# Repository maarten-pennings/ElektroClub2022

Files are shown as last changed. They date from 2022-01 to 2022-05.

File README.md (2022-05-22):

# ElektroClub2022

End-of-year project (2022) for the ElektroClub.

## Introduction

In my village I'm volunteer for an "ElectroClub" for children 8 to 12 years.
At the end of the (school) year we try to have a master piece for them, to remember the club.
In 2022 we wanted the year digits with flashing numbers; this is actually a copy of an old project:

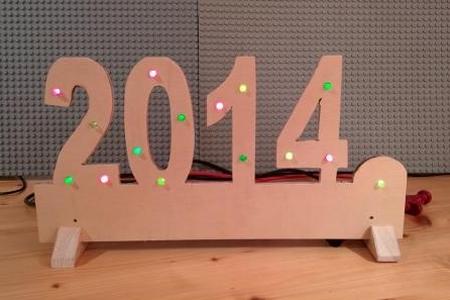
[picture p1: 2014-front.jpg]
front
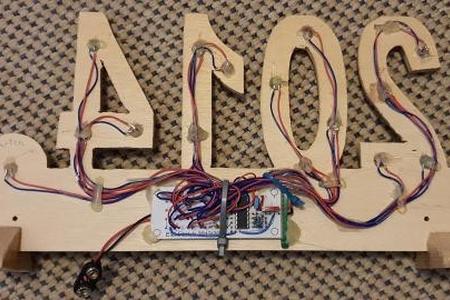
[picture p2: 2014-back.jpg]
back
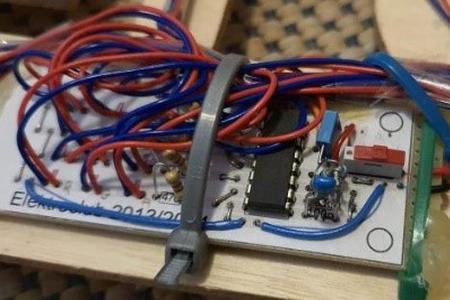
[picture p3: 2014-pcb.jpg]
pcb
  

What we remembered from 2014 is that creating the wooden panels, soldering all the LED wires, 
and gluing all wires in place, was too time consuming.
This year we will try a variation: designing the PCB using [EasyEDA](https://easyeda.com)
and manufacturing it via [JLCPCB](https://jlcpcb.com/). 
The biggest challenge is to get a nice rendering of the big digits 2022.

We have minutes of the project in [Word](ElektroClub2022-plan.docx) or [pdf](ElektroClub2022-plan.pdf) - sorry they are in Dutch.

## Schematics

The 2014 schematics were lost in time, so we needed to do some googling.
The heart of the circuit is the [4060 binary counter](https://www.ti.com/lit/ds/symlink/cd4060b.pdf):

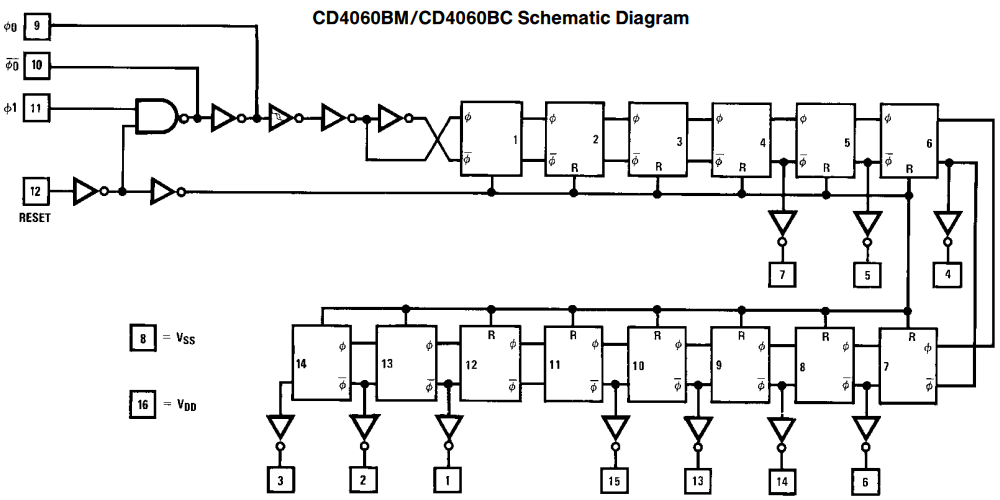
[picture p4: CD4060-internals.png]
4060 internals


The schematics is based on one from [buildcircuit](https://www.buildcircuit.com/diy-kit-8-happy-birthday-led-flashing-diy-kit-using-cd4060-and-music-chip/).
However, we have 5 groups of LEDs, not three. And we added some capacitors for stabilization.

We will use the 4060 outputs to flash the LEDs; here are some time [calculations](timing.xlsx).

We were initially puzzled by the diodes, we now believe they form a "wired OR", 
resetting the CD4060 when all three (five) transistor basis are high.
This is when the CD4060 reaches 0b...111 (0b...11111). 
In that situation all LEDs are off. 

In other words at the same moment all LEDs are switched off, 
the CD4060 is reset and outputs 0b...0000 and all LEDs are on.

Our final [schematic](schematic.pdf).

## Stand

I wanted the PCB to have small feet.
I made a [3D model](standmodel) to check the positions and lengths of the slots.

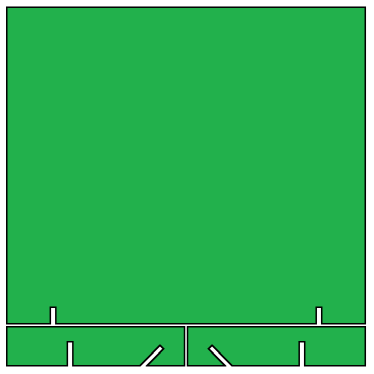
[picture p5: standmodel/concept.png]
slots
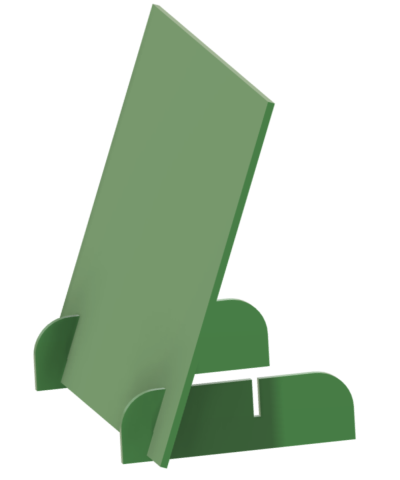
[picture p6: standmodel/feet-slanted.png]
model


## PCB (with fancy board outline and silk print)

A step that took quite some time was the [design](pcboutline) of the board outline.
This includes the big "2022" digits, that I wanted to cut out.
I made the design in Visio, because that can save to DXF, the format needed by the PCB tool.

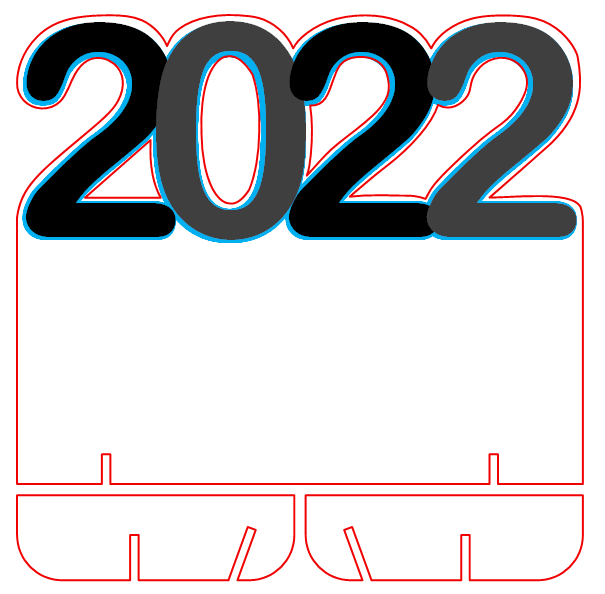
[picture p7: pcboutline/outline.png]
outline


The resulting PCB as a render, front and back side.

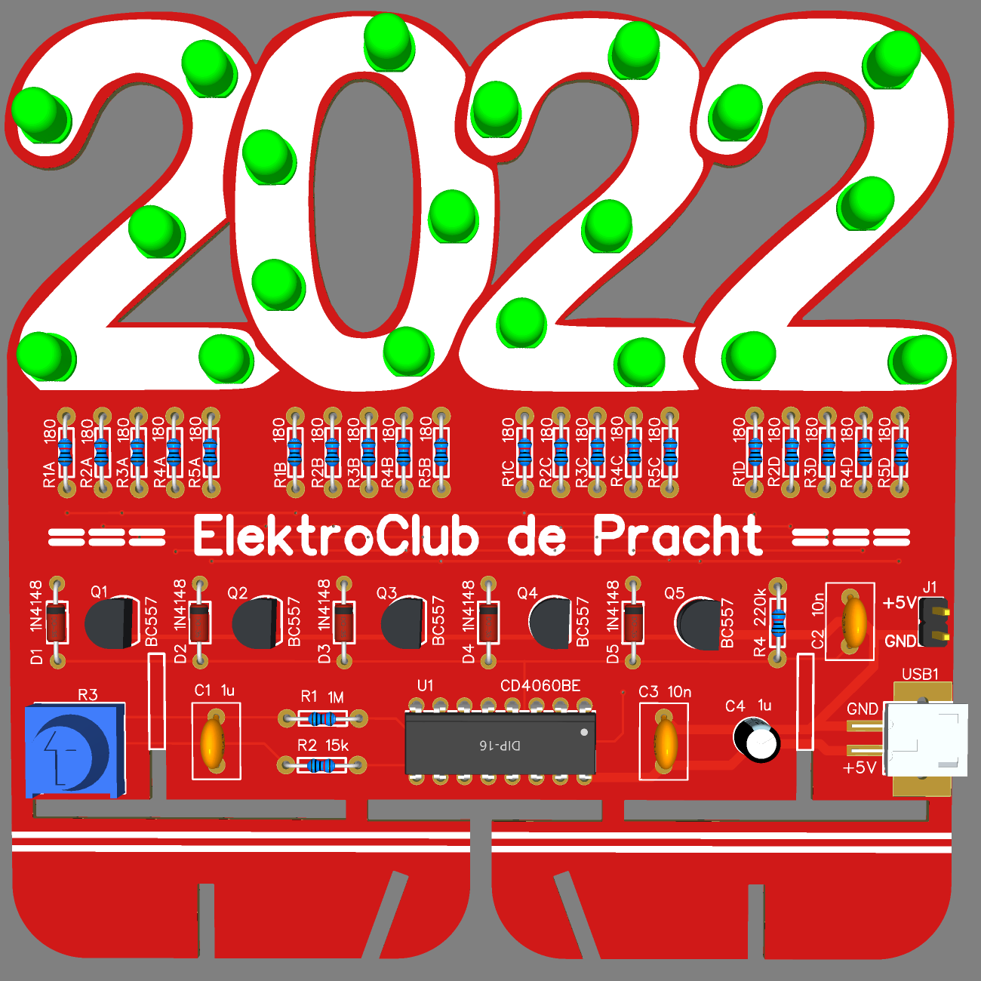
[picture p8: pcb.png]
PCB


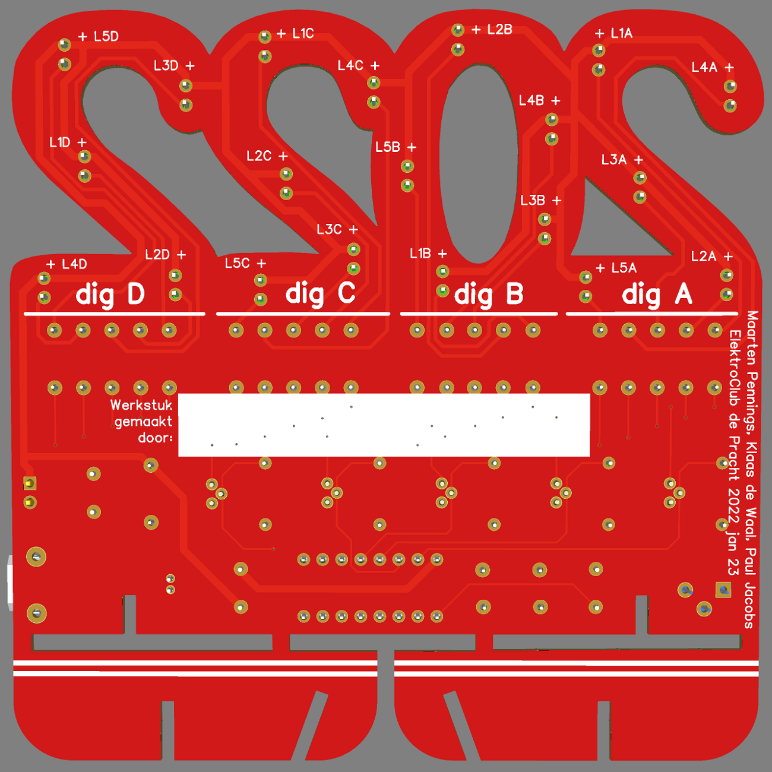
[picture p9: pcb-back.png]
PCB backside


Find the whole design on [oshwlab](https://oshwlab.com/maartenpennings/elektroclub2022).
The [gerber](Gerber_ElektroClub2022_pcb.zip) is also available separately.

## Order

I ordered 5 red, 10 green and 5 black at [JLCPCB](https://jlcpcb.com/); 
pricing: €1.76, €4.41, €3.53 respectively plus €15.85 shipping. Total €25.55.

The resulting PCBs are great looking. 

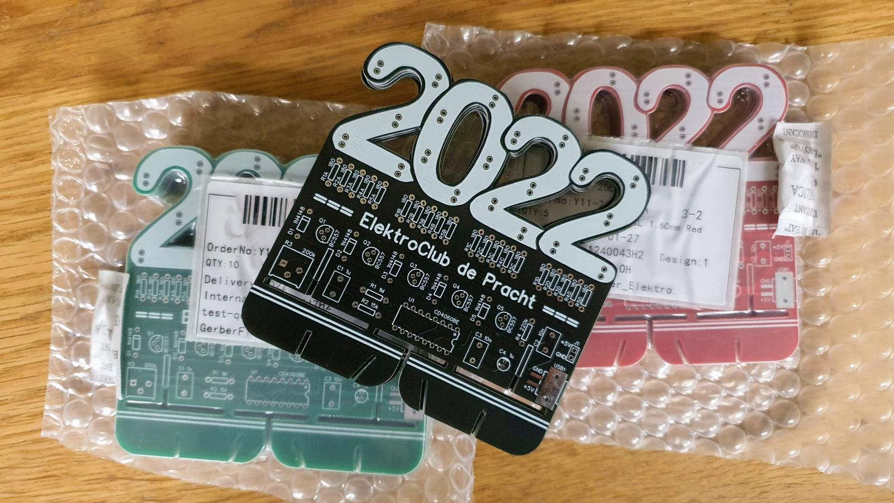
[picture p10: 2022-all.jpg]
PCBs


## Cost 

Find below the cost of the boards and components.
The LEDs, transistors, and resistors came from our stock, so I have added "guessed" prices.
We might have ordered too few IC sockets and/or USB connectors.

  | ID |      Name	     | Designator      |Quantity | For 20 boards | Stock (guessed) | Ordered  |
  |:--:|:---------------:|:---------------:|:-------:|:-------------:|:---------------:|:--------:|
  |  1 |  1u (ceramic )  | C1              | 1       |       20      |                 | [100(+100) for €3.02](https://www.aliexpress.com/item/1005001715033995.html) |
  |  2 |      10n        | C2,C3           | 2       |       40      |                 | 100 with (1) |
  |  3 |   1u (elco)     | C4              | 1       |       20      |                 | [50 for €1.90](https://www.aliexpress.com/item/1005002842732971.html) |
  |  4 |     1N4148      | D1,D2,D3,D4,D5  | 5       |      100      |                 | [200 for €2.01](https://www.aliexpress.com/item/1005003540554760.html) |
  |  5 | HDR-M-2.54_1x2  | J1              | 1       |       20      |    Not mounted  | Not mounted |
  |  6 | LED-TH-5mm      | L1A,L1B,L1C,L1D |         |               |                 | |
  |    |                 | L2A,L2B,L2C,L2D |         |               |                 | |
  |    |                 | L3A,L3B,L3C,L3D |         |               |                 | |
  |    |                 | L4A,L4B,L4C,L4D |         |               |                 | |
  |    |                 | L5A,L5B,L5C,L5D | 20      |      400      | [500 for €4.66](https://www.aliexpress.com/item/1005003483614644.html) | |
  |  7 |     BC557       | Q1,Q2,Q3,Q4,Q5  | 5       |      100      | [100 for €2.24](https://www.aliexpress.com/item/32868211649.html) | |
  |  8 |       1M        | R1              | 1       |       20      | [100(+100+100+100) for €3.80](https://www.aliexpress.com/item/32979849787.html) | |
  |  9 |      180        | R1A,R1B,R1C,R1D |         |               |                 | |
  |    |                 | R2A,R2B,R2C,R2D |         |               |                 | |
  |    |                 | R3A,R3B,R3C,R3D |         |               |                 | |
  |    |                 | R4A,R4B,R4C,R4D |         |               |                 | |
  |    |                 | R5A,R5B,R5C,R5D | 20      |      400      |    100 with (8) | |
  | 10 |      15k        | R2              | 1       |       20      |    100 with (8) | |
  | 11 | 200k (potmeter) | R3              | 1       |       20      |                 | [25 for €5.48](https://www.aliexpress.com/item/32783054938.html) |
  | 12 |     220k        | R4              | 1       |       20      |    100 with (8) | |
  | 13 |   CD4060BE      | U1              | 1       |       20      |                 | [30 for €2.52](https://www.aliexpress.com/item/1005001345739246.html) |
  | 14 |micro USB (2 pin)| USB1            | 1       |     **20**    |                 | [**20** for €2.00](https://www.aliexpress.com/item/32931657320.html) |
  | 15 |  dip 16 socket  | (U1)            | 1       |     **20**    |                 | [**20** for €1.75](https://www.aliexpress.com/item/1005001403007175.html) |
  | 16 |  ziplock bags   | -               | 1       |       20      |                 | [100 for €3.64](https://www.aliexpress.com/item/1005003813481837.html) |
  | 17 |      pcb        | -               | 1       |       20      |                 | [20 for €25.55](https://oshwlab.com/maartenpennings/elektroclub2022) |
  |    |                 |                 |         |               |          €10.70 | **€47.87** |
  |    |                 |                 |         |               |                 | €58.57 (**€2.93/piece**) |

## Instructions

There is an instruction leaflet for assembling the PCB:
a [doc](ElektroClub2022-manual.docx) or [pdf](ElektroClub2022-manual.pdf) version.
Since the leaflet is for the children, it is in Dutch.

## Final result

The assembled board looks like this (sorry, potmeter is on backorder).

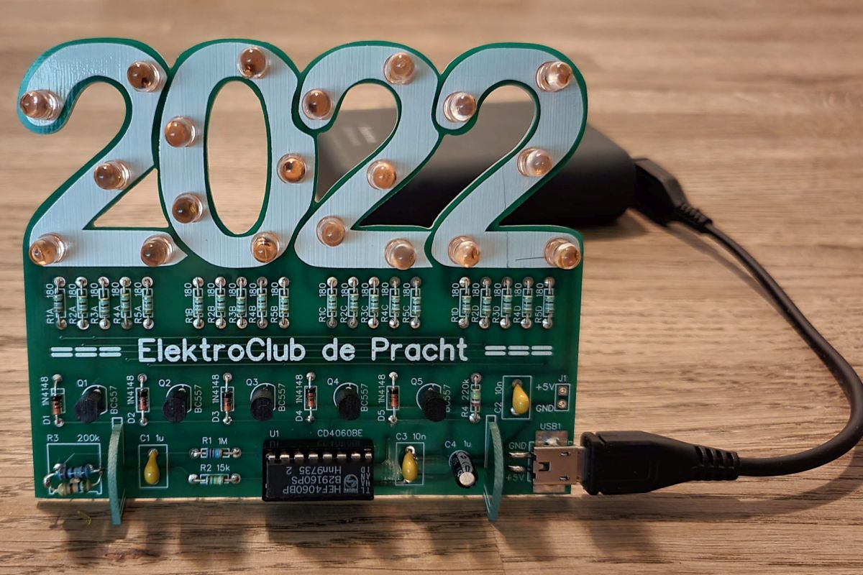
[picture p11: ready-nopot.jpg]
Ready no pot


For a video check [YouTube](https://www.youtube.com/watch?v=dqfvwsGTvYA).

## Problems

The result (see video) looks ok, but we found some [issues](debug).

(end)

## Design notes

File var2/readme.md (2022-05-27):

# Variant 2

The CD4060 is hard to obtain, the reset circuit is hard to get correct, 
the blinking patterns are not very random. Why not replace the CD4060 with an ATtiny85.

## Firmware

I wrote the [multiblink](multiblink) firmware.
It is tested on Nano and ATtiny85.

I used a [Nano to flash](https://makersportal.com/blog/2018/5/19/attiny85-arduino-board-how-to-flash-the-arduino-bootloader-and-run-a-simple-sketch) the ATtiny85.

## Schematics

The ATtiny85 has 8 pins, 2 are for power, one is for reset, so 5 left.
We have 5 groups of LEDs, so they can be hooked to those 5 GPIO pins.

However, we wanted a switch to control the speed or blinking pattern.
The first idea was to use the RESET pin for that. 
But once the RESET pin is reprogrammed, it is hard to reflash the ATtiny85.

Instead we opted for time multiplexing, the output pins, using them also for input.

See the [schematics](Schematic_ElektroClub2022tiny.pdf).

## Breadboard

The ATtiny85 with firmware, group drivers and switches is tested on a breadboard.
Here is demo [video](https://www.youtube.com/watch?v=RSclDXem_cg).
Speed varies over 100ms, 200ms, 400ms, 800ms, 1600ms, 3200ms, and 6400ms.
Patterns are ALL, HALF024, HALF34, BIN, WALK1, WALK2, WALK3, RND, RNDHI.

## In-situ

Next step was to test the ATtiny in the actual PCB. I took out the 4060
and wired the 4060 pins to a breadboard with the ATtiny85 (and the two switches).

The lower switch controls pattern mode: 
flash ALL, HALF (0+1+2 then 3+4), BINARY, WALK1, WALK2, FILL, RND, RNDMED (min 2 leds on, max 3). 
The upper switch controls the blink time 100, 200, 400, 800, 1600, 3200, and 6400ms. 

This is the [video](https://youtu.be/QG9YBovyWns).

## Impression

A possible impression for the new PCB

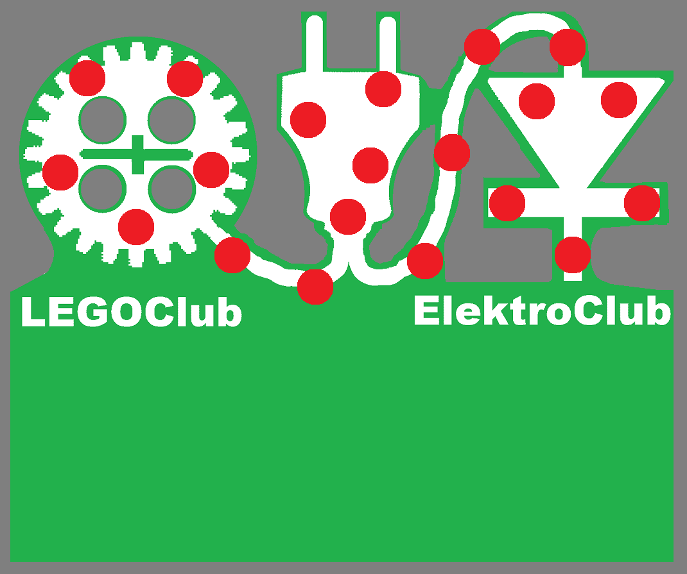
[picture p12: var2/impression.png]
Impression


(end)

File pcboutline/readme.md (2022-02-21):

# PCB outline

Non-rectangular board outline and fancy silk print
in [EasyEDA](https://easyeda.com) and [JLCPCB](https://jlcpcb.com/). 

Find the design on [oshwlab](https://oshwlab.com/maartenpennings/elektroclub2022).

## Introduction

We want big digits.
Those digits need to stand out.
We achieve this in two ways:
 - partially "cut them out", i.e. complex PCB outline
 - "paint" them, either via silk print or via metal
 
[EasyEDA](https://easyeda.com) has an import mechanism for both.
For an outline, it needs a vector description via a so-called [DXF file](https://en.wikipedia.org/wiki/AutoCAD_DXF).

For the silk print it needs a bitmap via a jpg, png, gif, bmp or SVG file.

I had one tool that support both, VISIO.

## Visio

I've drawn the 4 digits in Visio using "Arial Rounded MT Bold" at 150pt.
At this size, the four digits span 100mm, the target width of the PCB.

I rendered the digits twice, once bold (blue) and once non-bold (black/gray).
The black/gray will be exported as png for EasyEDA silk screen.

I used the blue as a reference for a hand crafted outline.
The blue (bold) was a bit bigger than black (non-bold) but not much bigger, 
so my handcrafted outline (Visio line tool) is about 1mm away from the blue.
The drawing includes the slots and the feet from the 3D model.

Here is a visualisation of the [Visio](outline.vsdx) drawing

Outline.

I did two separate exports, the red lines to a [DXF file](outline.dxf)
and the black/gray digits to a [png file](letters.png).

## Outline

The outline (and especially board cut-outs are the hardest).
In the [EasyEDA](https://easyeda.com) PCB editor, import the DXF file.

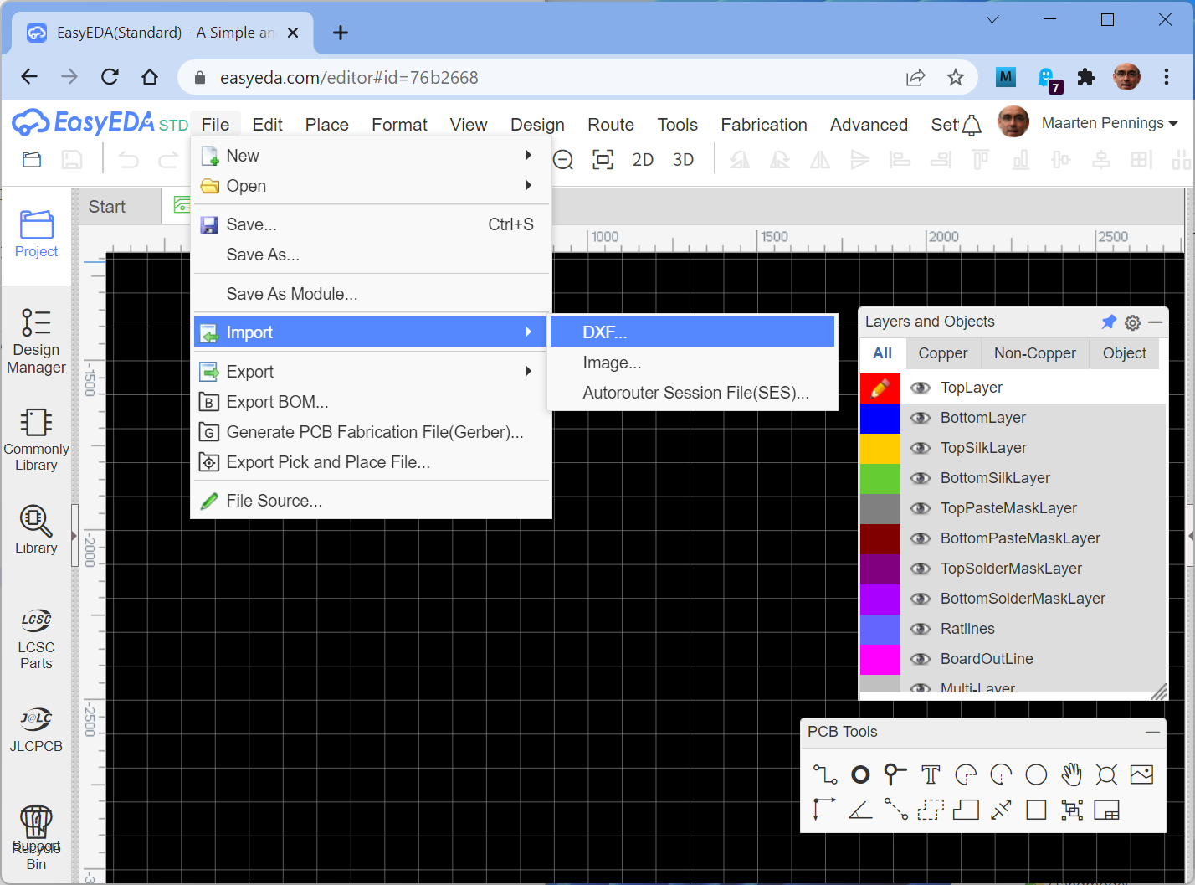
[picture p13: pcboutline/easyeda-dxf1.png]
Outline - dialog


Press `Select a DXF file...` and browse to `outline.dxf`.
Also make sure to import on layer `BoardOutLine`.

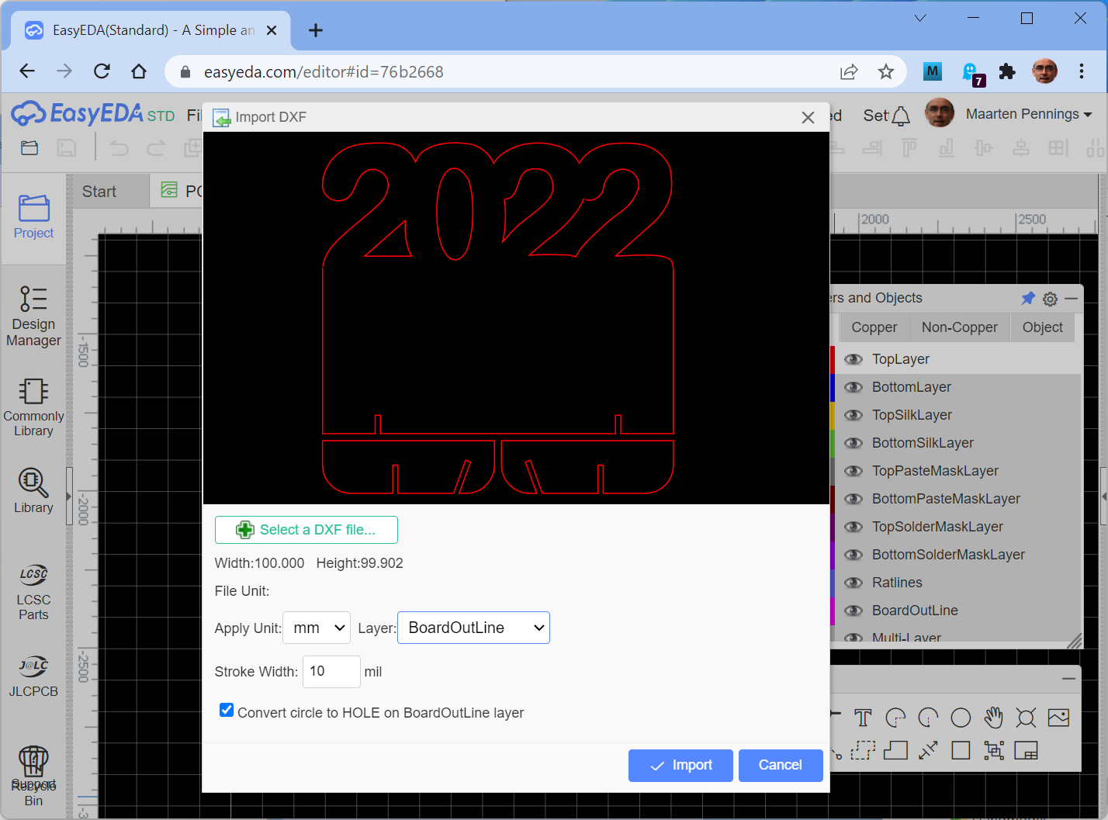
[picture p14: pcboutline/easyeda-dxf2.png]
Outline - outline


Note that a DXF file has units and length, so the outline has the correct dimensions.
You might want to use `Place > Set canvas Origin > By Mouse Location` to set the origin
(and use middle-mouse-button with moving the mouse to **pan** and ctrl-middle-mouse-button with a wheel-roll to **zoom**).

If you click the outline (purple line) with the mouse it will light up white to indicate selection.
What we do see is that the outline is not one curve but multiple segments 
(in the image below, we see a selection of a small wedge).
Even more importantly, the segments are not fully connected (in the image below red encircled).

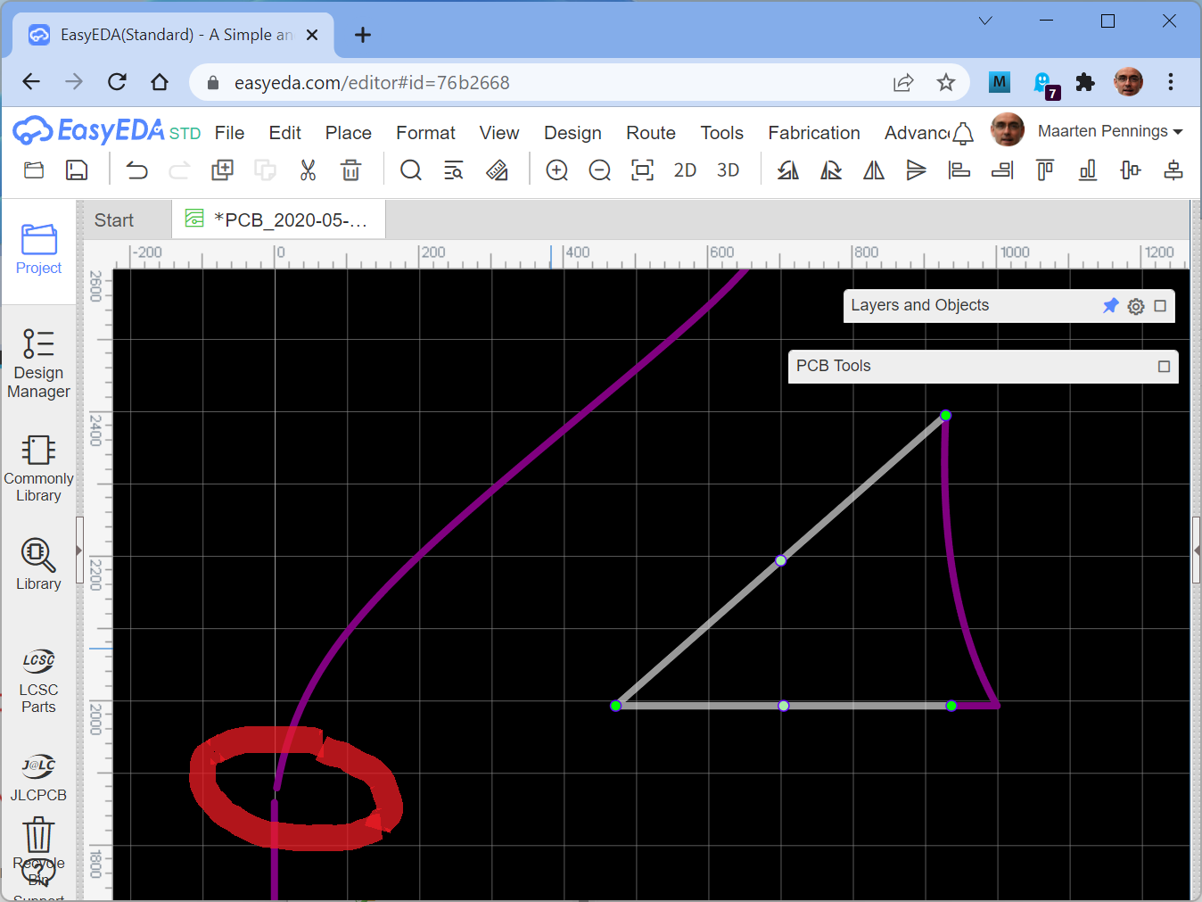
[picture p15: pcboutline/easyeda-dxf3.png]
Outline - connected


You can drag a green dot of one segment to the end of another segment. I suggest to also drag the end of that other segment
so that both ends snap to the same grid point.

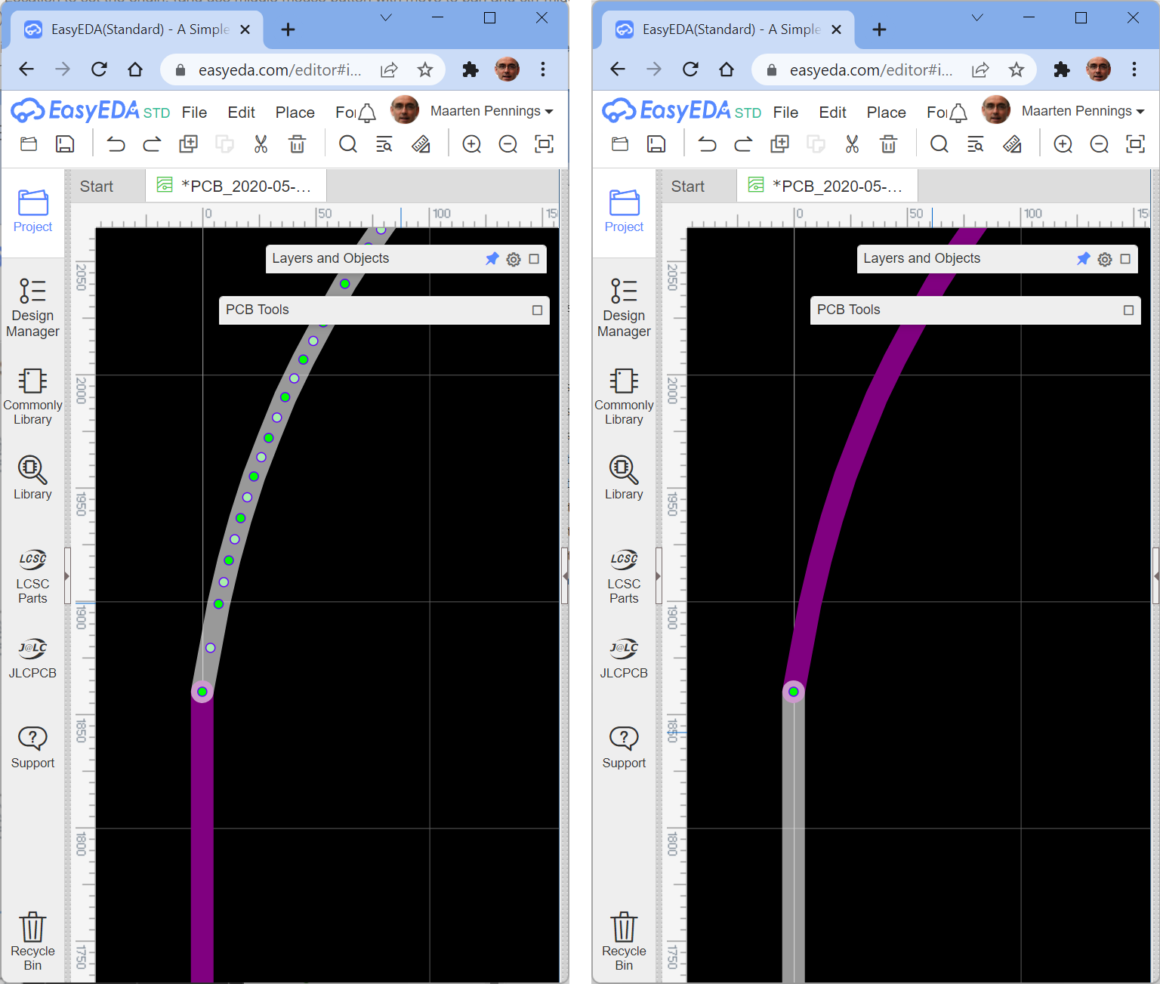
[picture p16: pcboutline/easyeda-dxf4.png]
Outline - same grid point


For the inner holes we need to go one step further. 
Not only do the segments need to be _connected_ (overlapping end-points), they need to be _continuous_.
So after you manually moved the end-points of the segments to overlap, select all the segments that make up one hole.
Either drag a rectangle around all, or use CTRL-click to add (actually toggle) segments to the selection.
Once all segments are selected right-click on the black canvas (not on a segment!) and select `Combine to Continuous Track`.

Note: try right click again with the segments/track selected, if the `Combine to Continuous Track` remains in the right click
menu, the end-points did not overlap well enough - I suggest to drag all endpoints to a grid point.

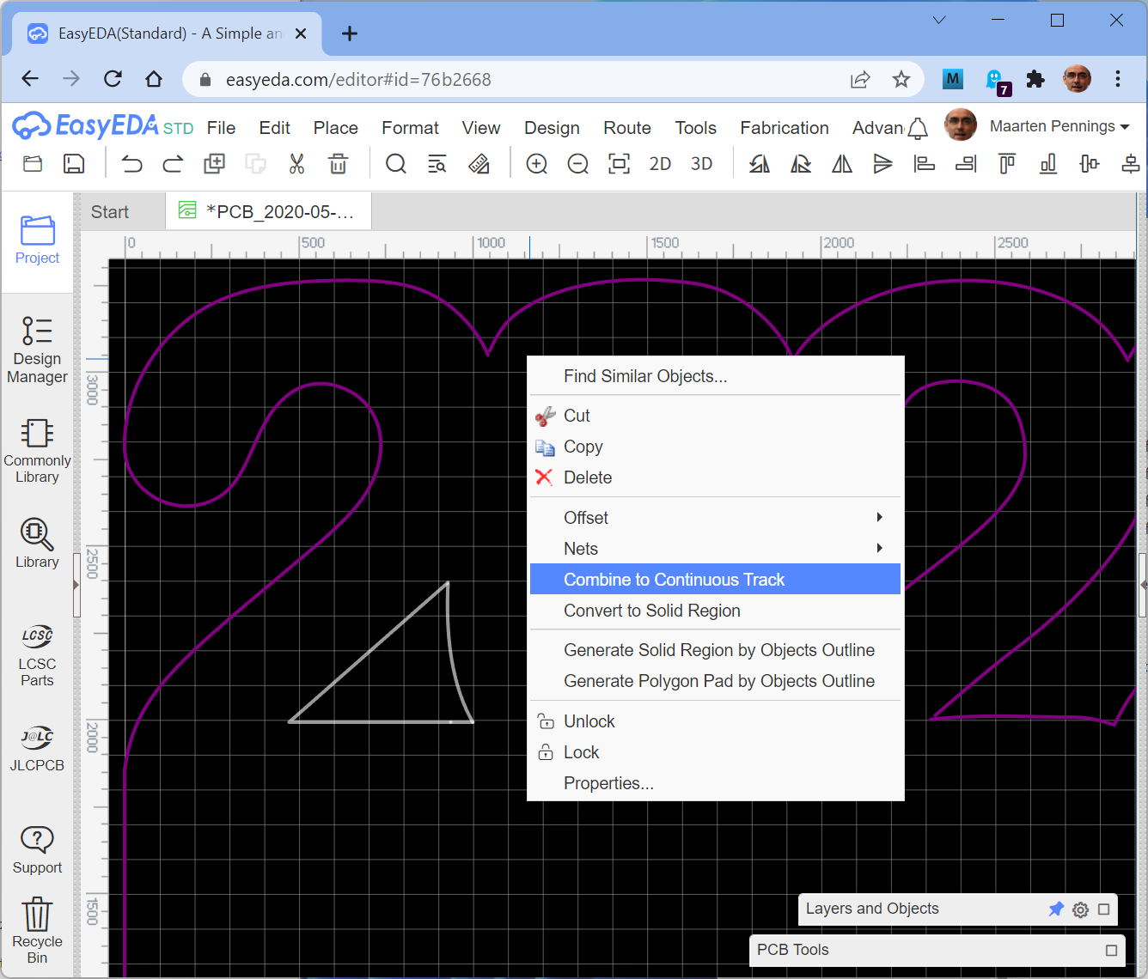
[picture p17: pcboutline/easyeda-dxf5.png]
Outline - continuous


Once that is done, the track can be converted to board cutout.
Select the track, use the right-click menu and select `Convert to Board Cutout`.

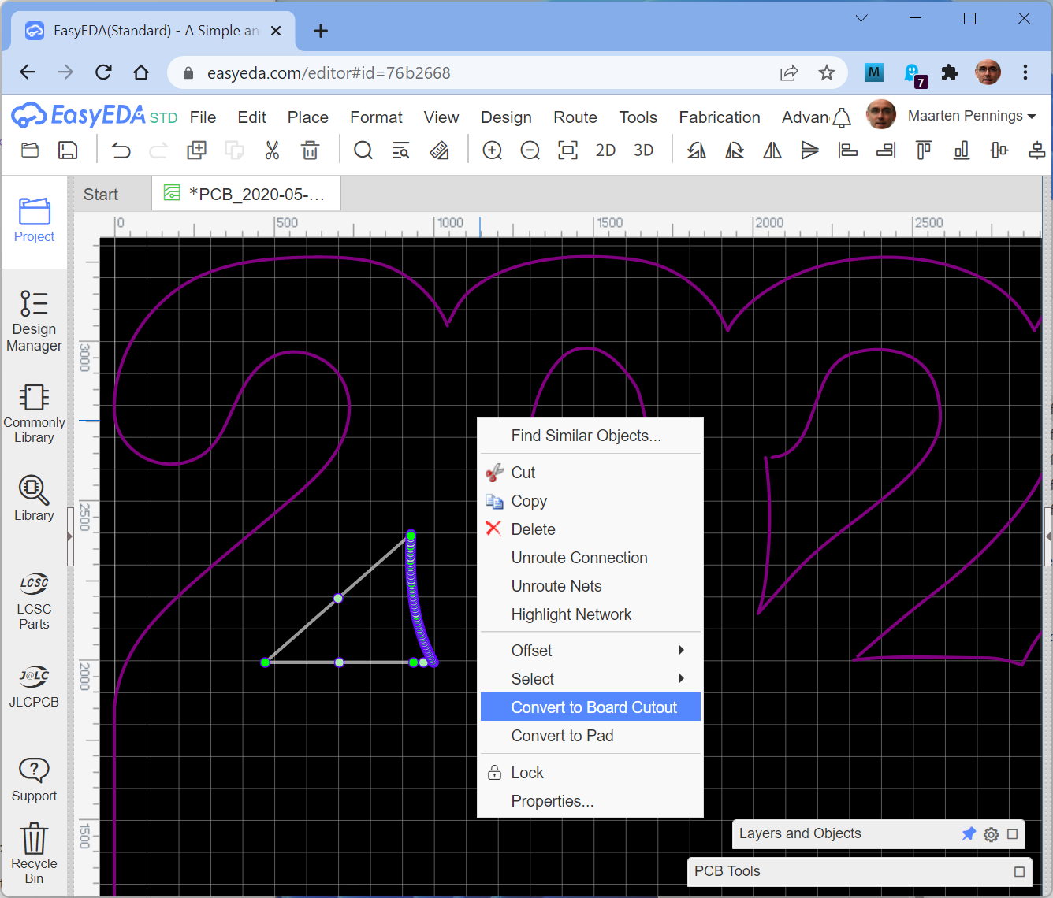
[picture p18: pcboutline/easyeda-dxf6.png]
Outline - board cutout


If the polygon (cutout) is _not_ filled gray, the track was not closed. Drag end-points to make sure they overlap;
again I suggest to drag all endpoints to a grid point.

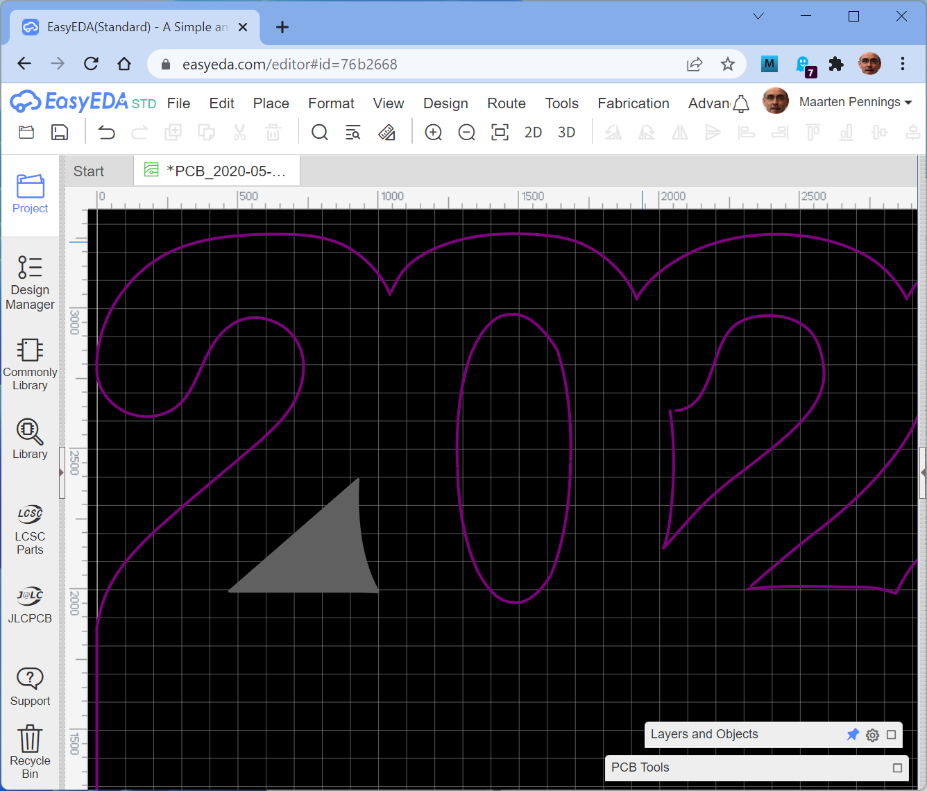
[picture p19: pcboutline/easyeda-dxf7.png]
Outline - gray


The 3D View menu is a good way to check the cutout was successful.

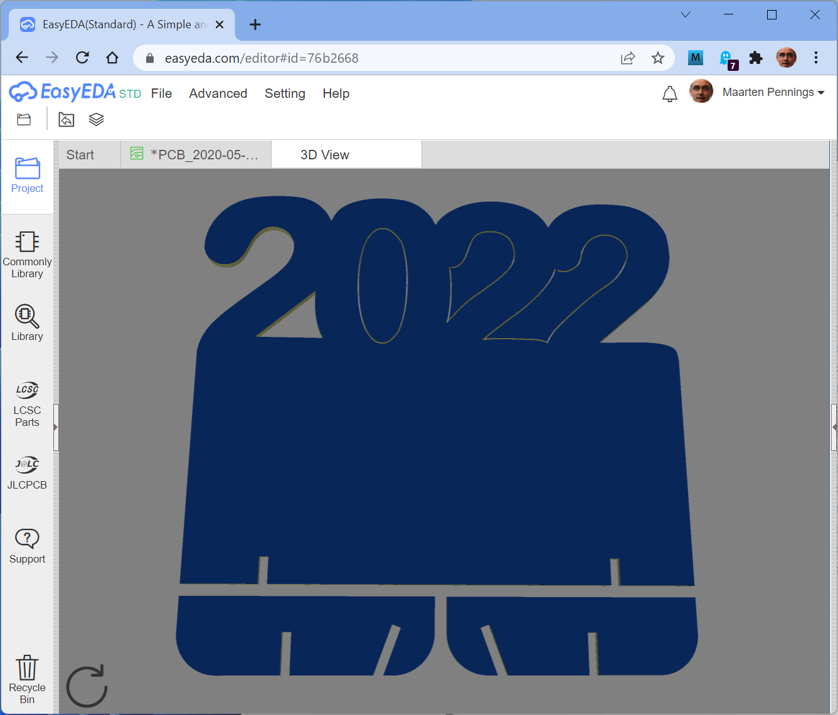
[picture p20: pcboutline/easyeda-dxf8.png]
Outline - 3D


## Silk print

In an image editing programs (MS Paint), I added some white between the digits.

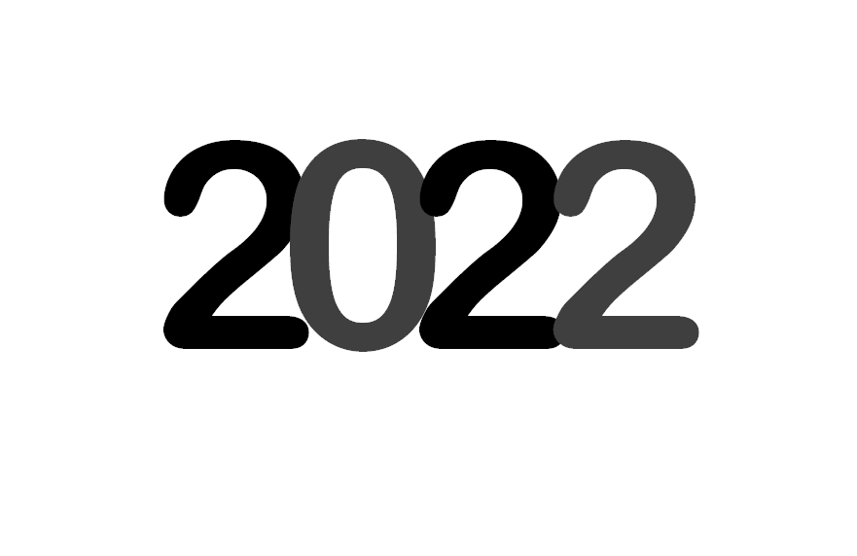
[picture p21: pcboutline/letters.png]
letters before
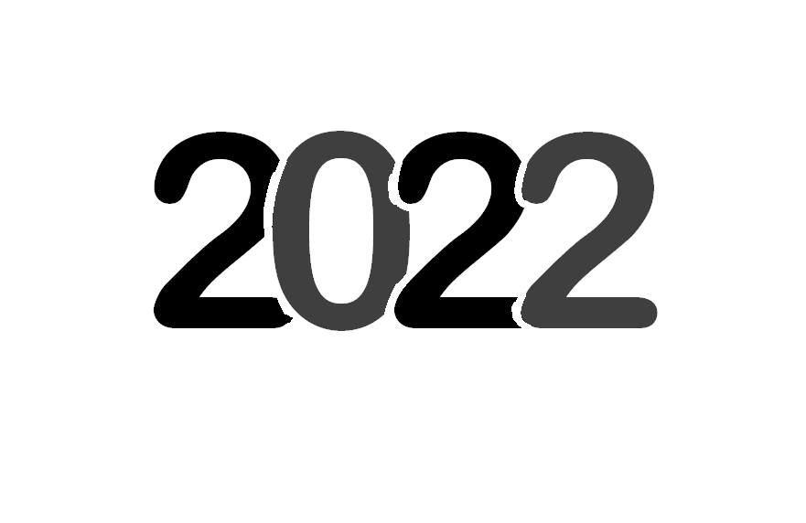
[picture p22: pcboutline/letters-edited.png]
letters after
 

In the [EasyEDA](https://easyeda.com) PCB editor, start by selecting the 
correct layer for the import - in our case the `TopSilkLayer`. 

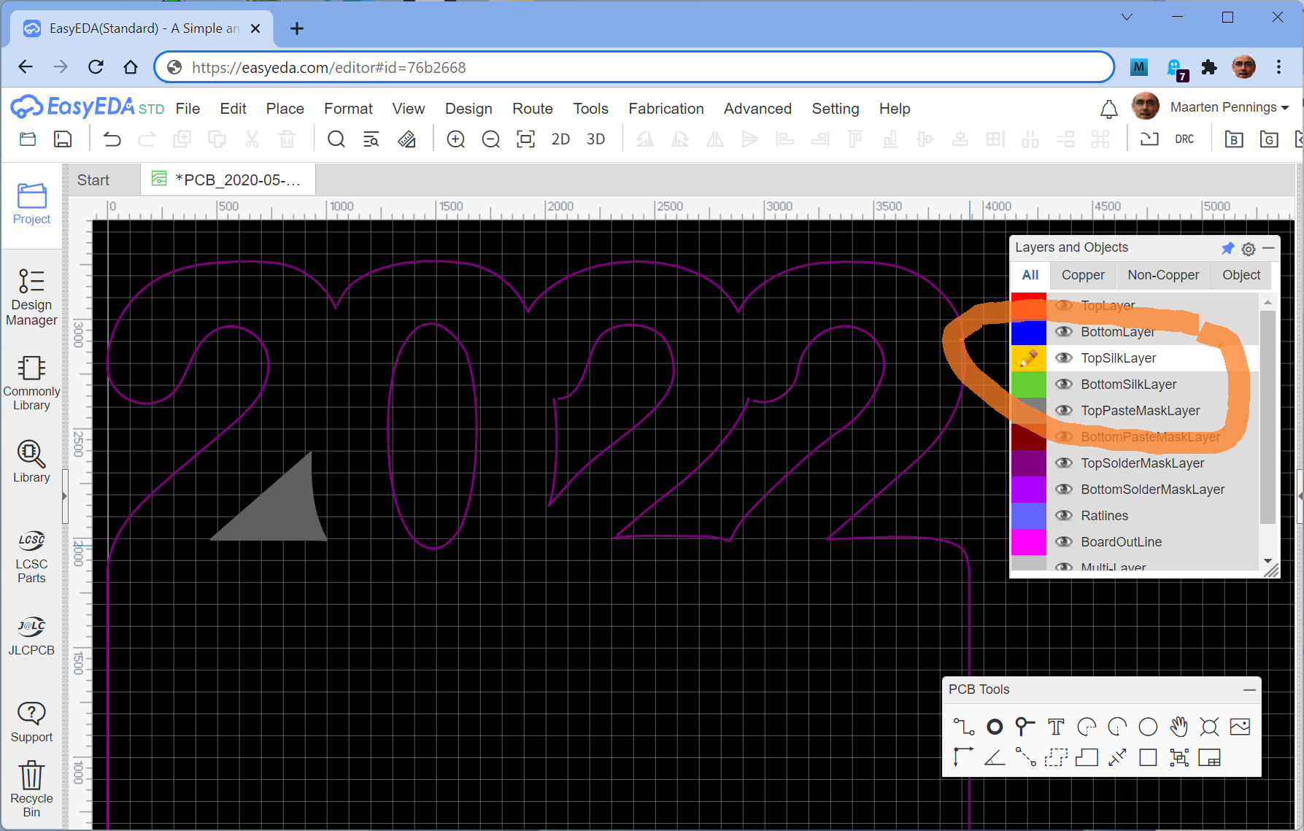
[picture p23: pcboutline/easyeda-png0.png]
Silk print - top silk layer


Next start the dialog to import the png file. 

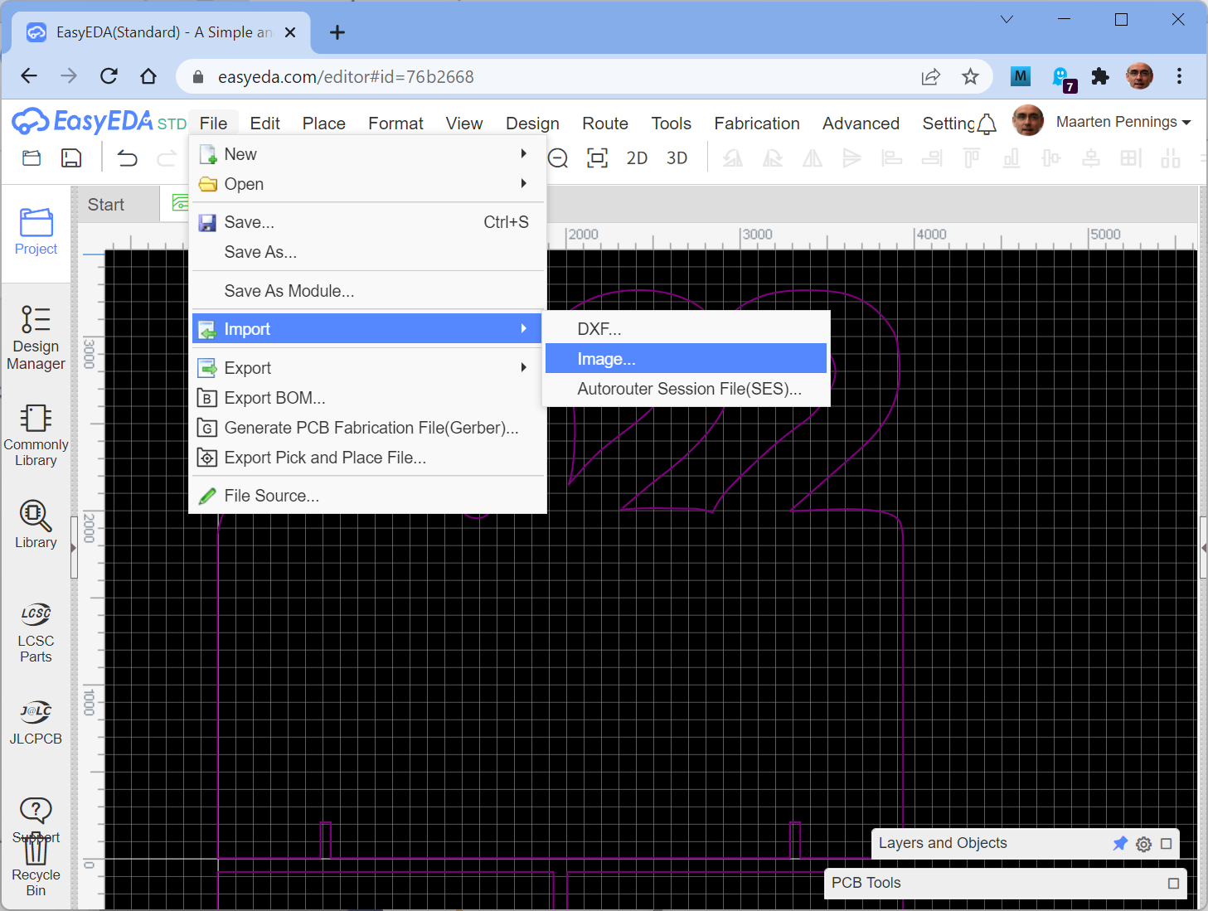
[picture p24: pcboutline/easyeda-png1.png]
Silk print - dialog


Select `letters-edited.png` as image file.
Note that EasyEDA doesn't care about black or gray, it imports the png in two-tone (black and white) - this
is governed by the `Color Tolerance` slider.

Bitmap images do not carry real world size. So it is important to measure (in the original Visio file)
what the width of the `2022` is. In our case that is 97.4mm, so fill that in on the bottom (and select `mm`).
The aspect ratio is maintained.

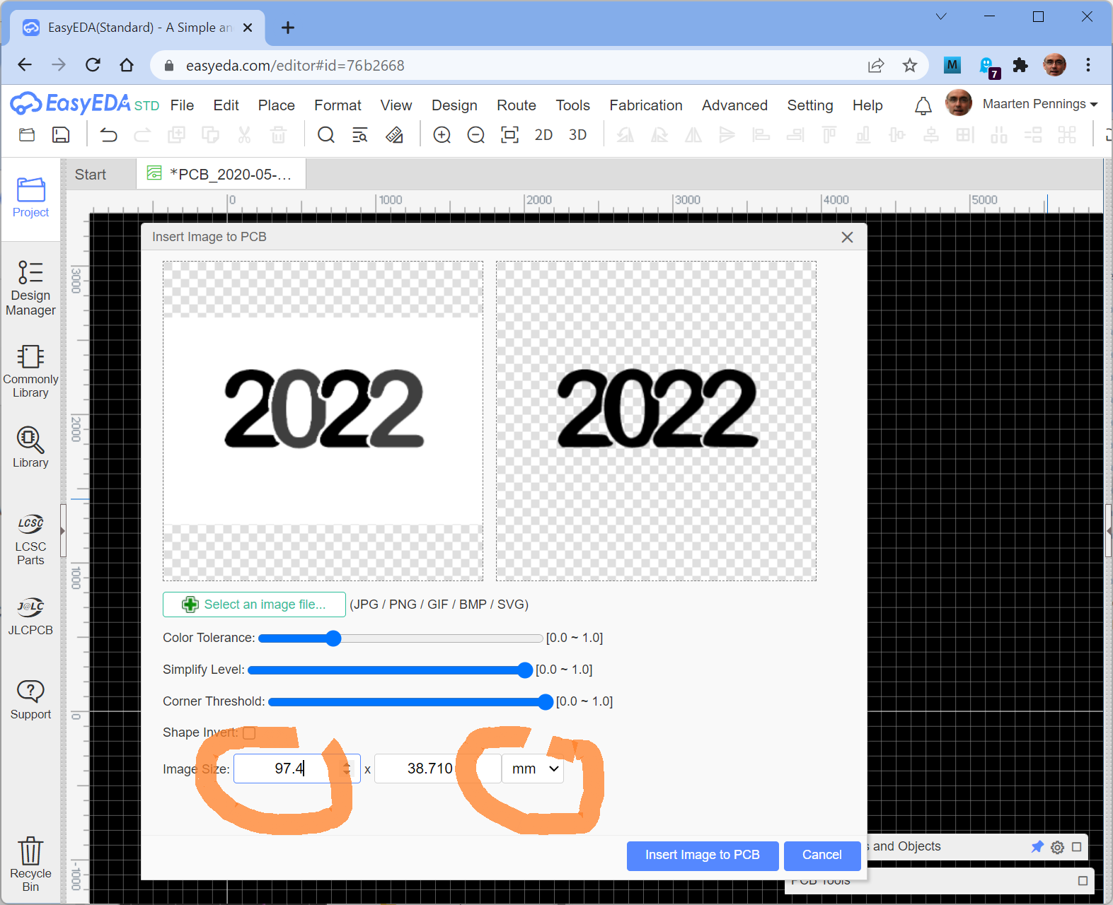
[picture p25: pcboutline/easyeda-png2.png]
Silk print - size


Now drag the image to the correct position.
If the image is a bit off in size, or on the wrong layer, right click and select `Properties`.
In the window that pops-up the width, height, layer can be changed.
Note that here the aspect ratio is _not_ maintained.
You can not select the units in this windows; our 97.4mm is rendered as 3833mil.

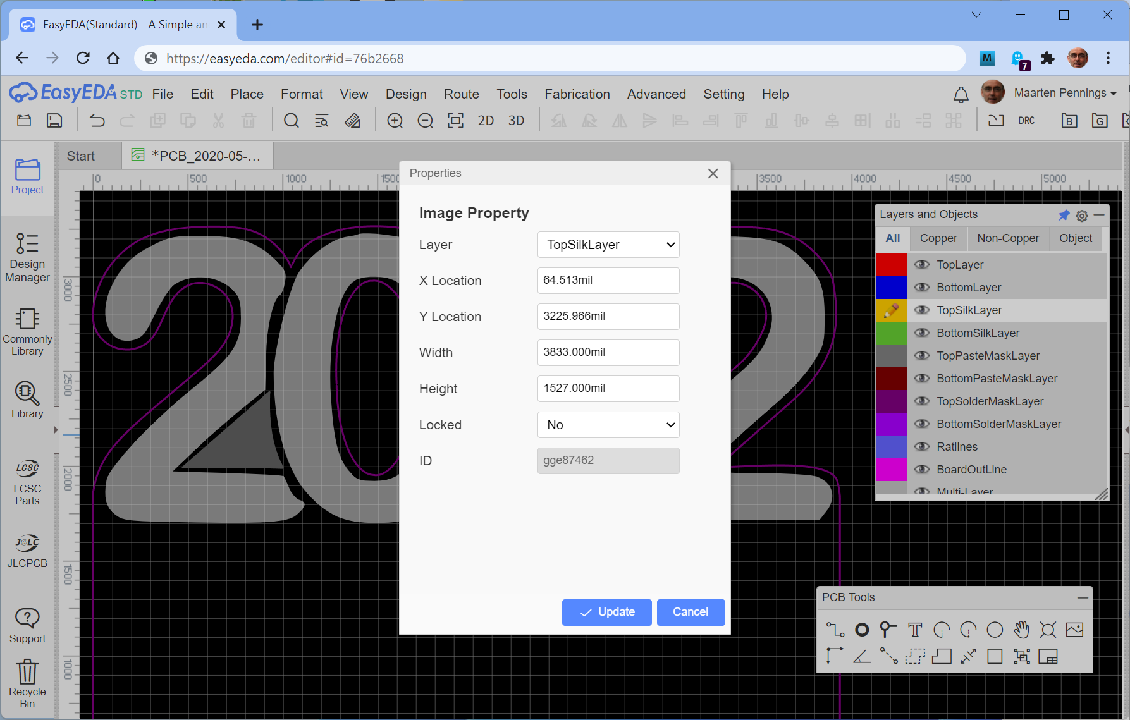
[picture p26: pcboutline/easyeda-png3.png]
Silk print - properties


This is also available in the panel on the right `View > Right-Hand Panel` - assuming the image is selected (white).

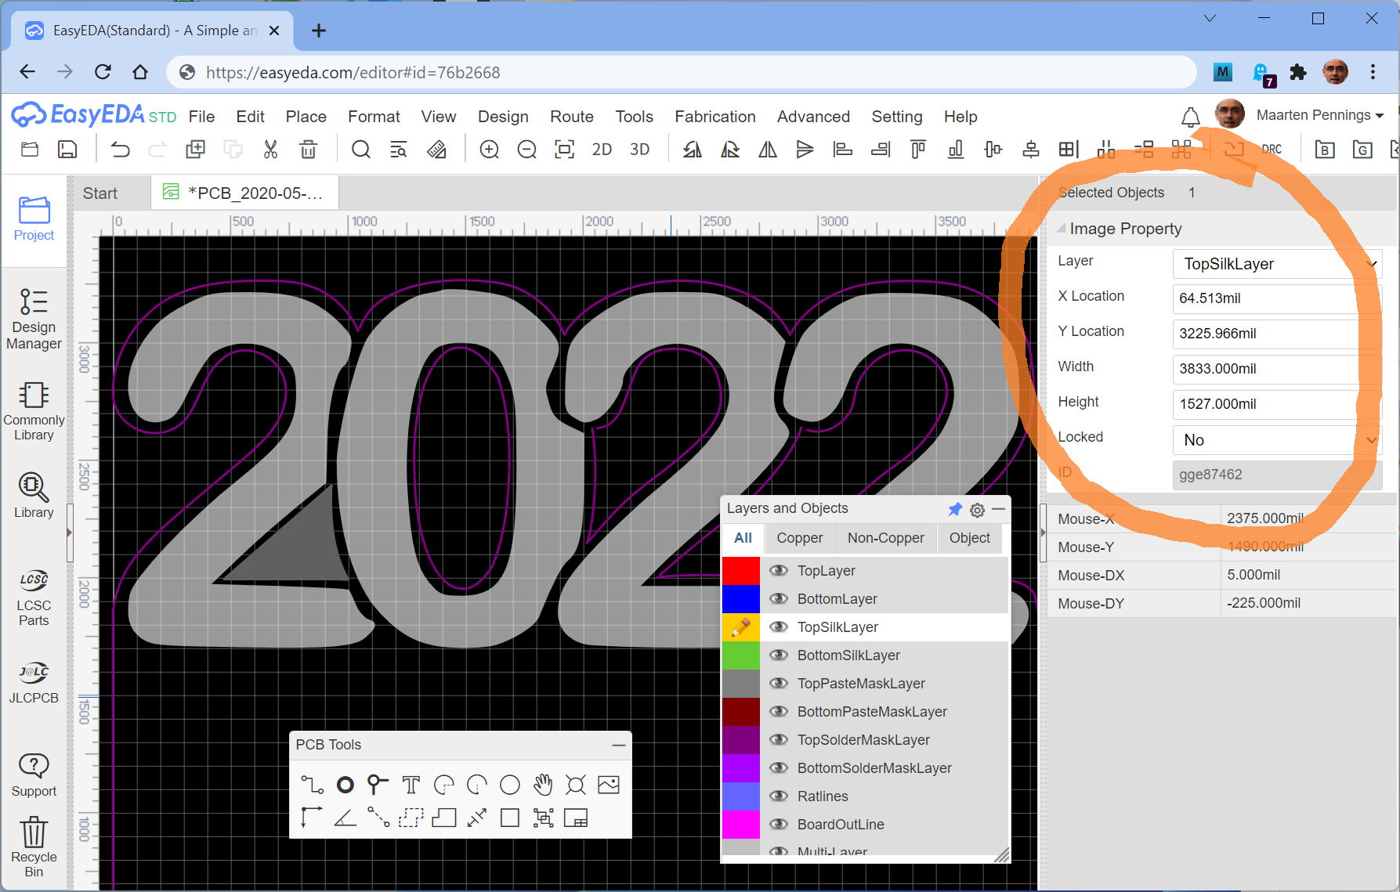
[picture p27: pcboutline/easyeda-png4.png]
Silk print - panel


## Warning

The 3D view in EasyEDA is nicely rendering our design.

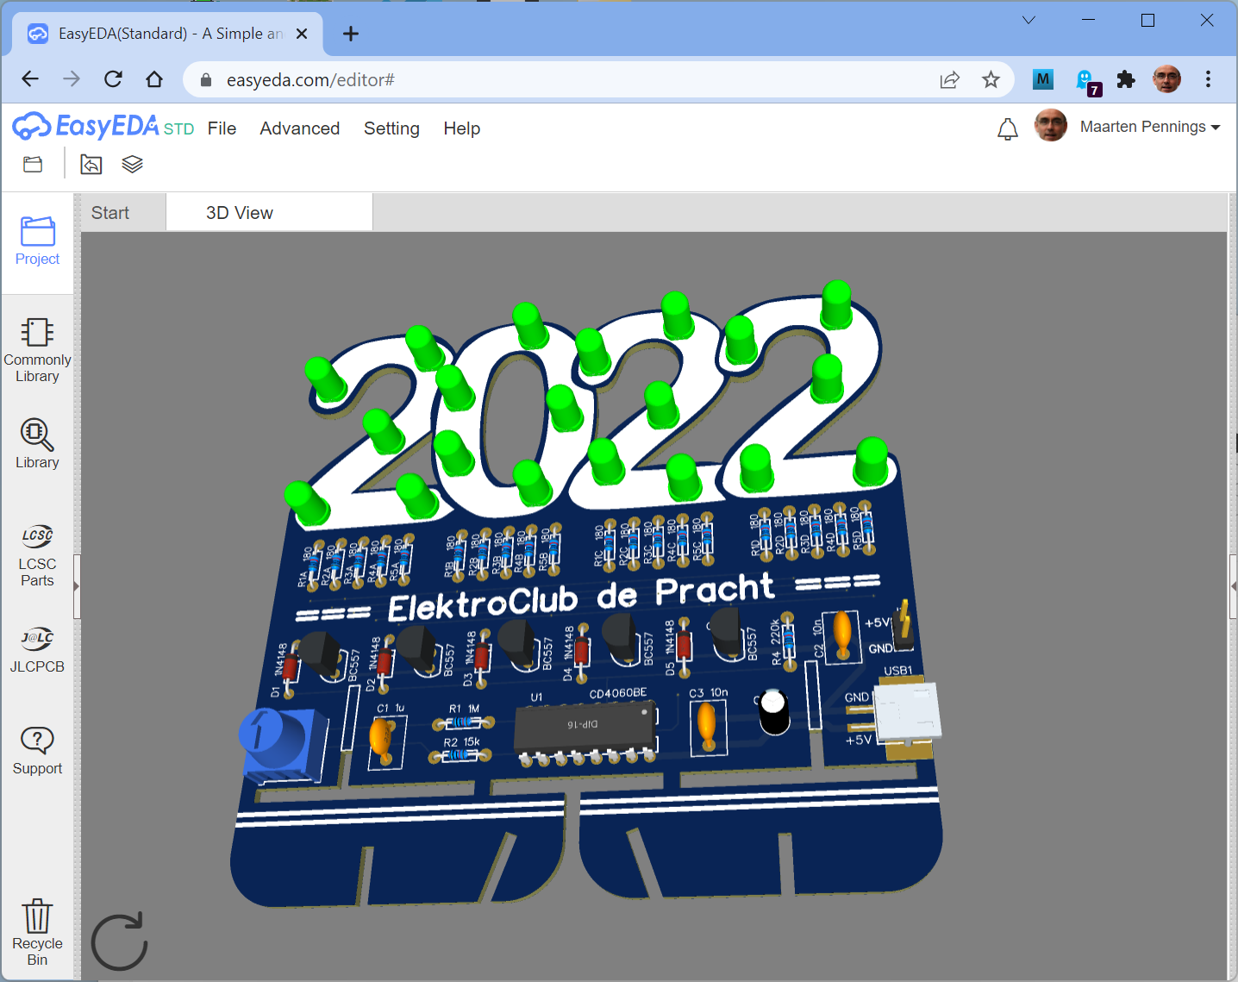
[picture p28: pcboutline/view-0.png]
3D


When we want to manufacture, we generate a Gerber file. That also looks fine.

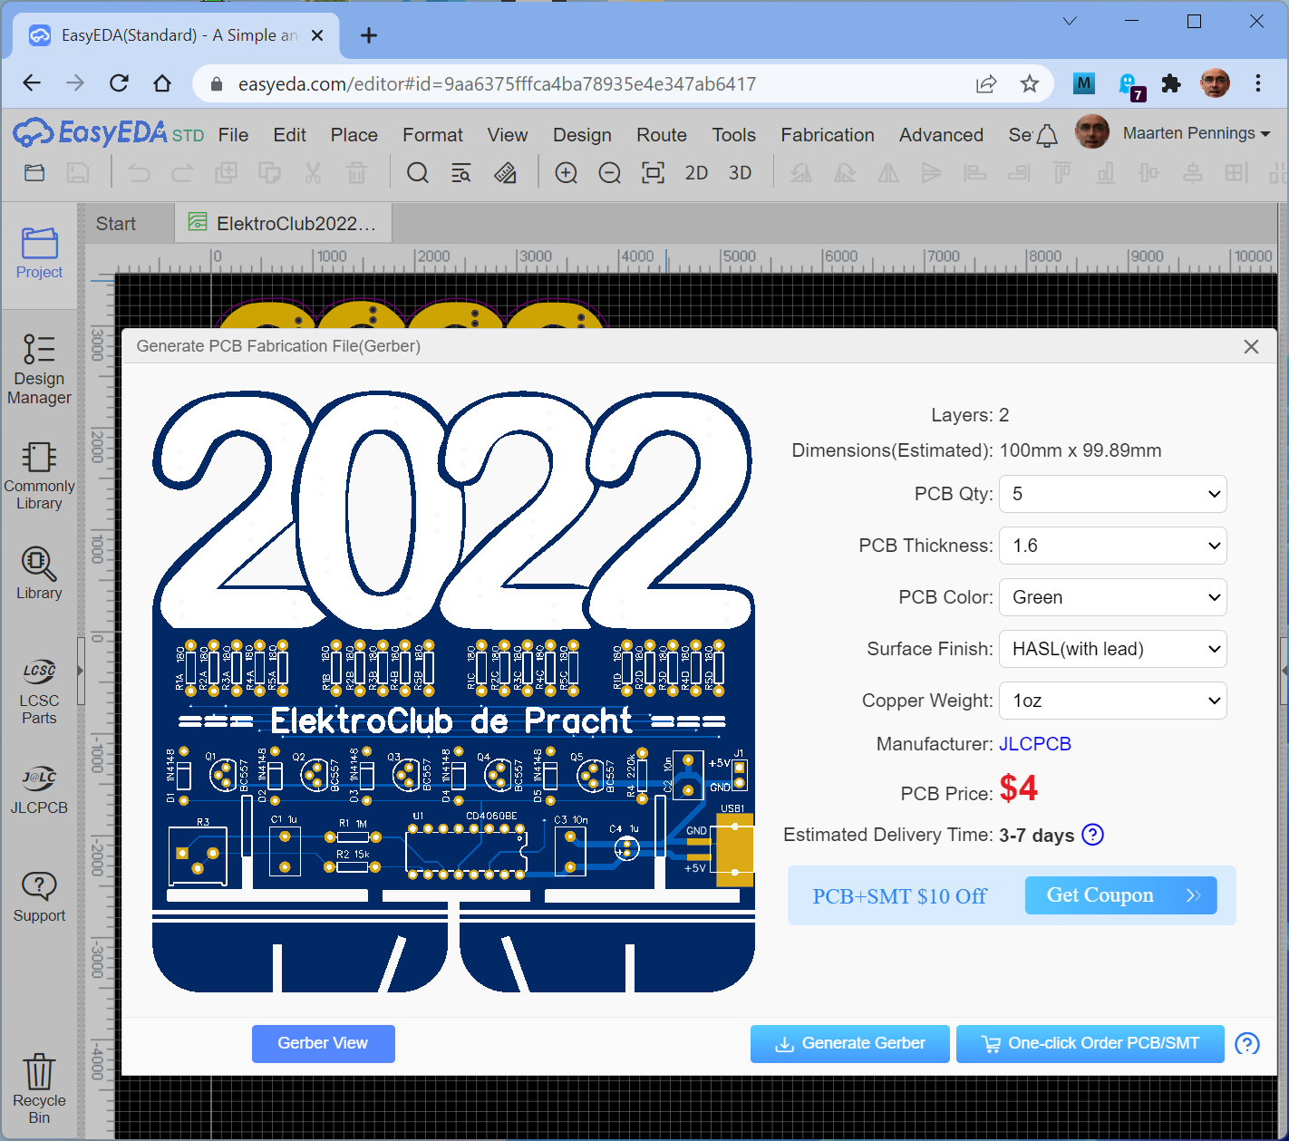
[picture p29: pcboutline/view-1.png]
Gerber in EasyEDA


When we import the Gerber in [JLCPCB](https://jlcpcb.com/), we see that the internal cutout holes
are not rendered correctly. 

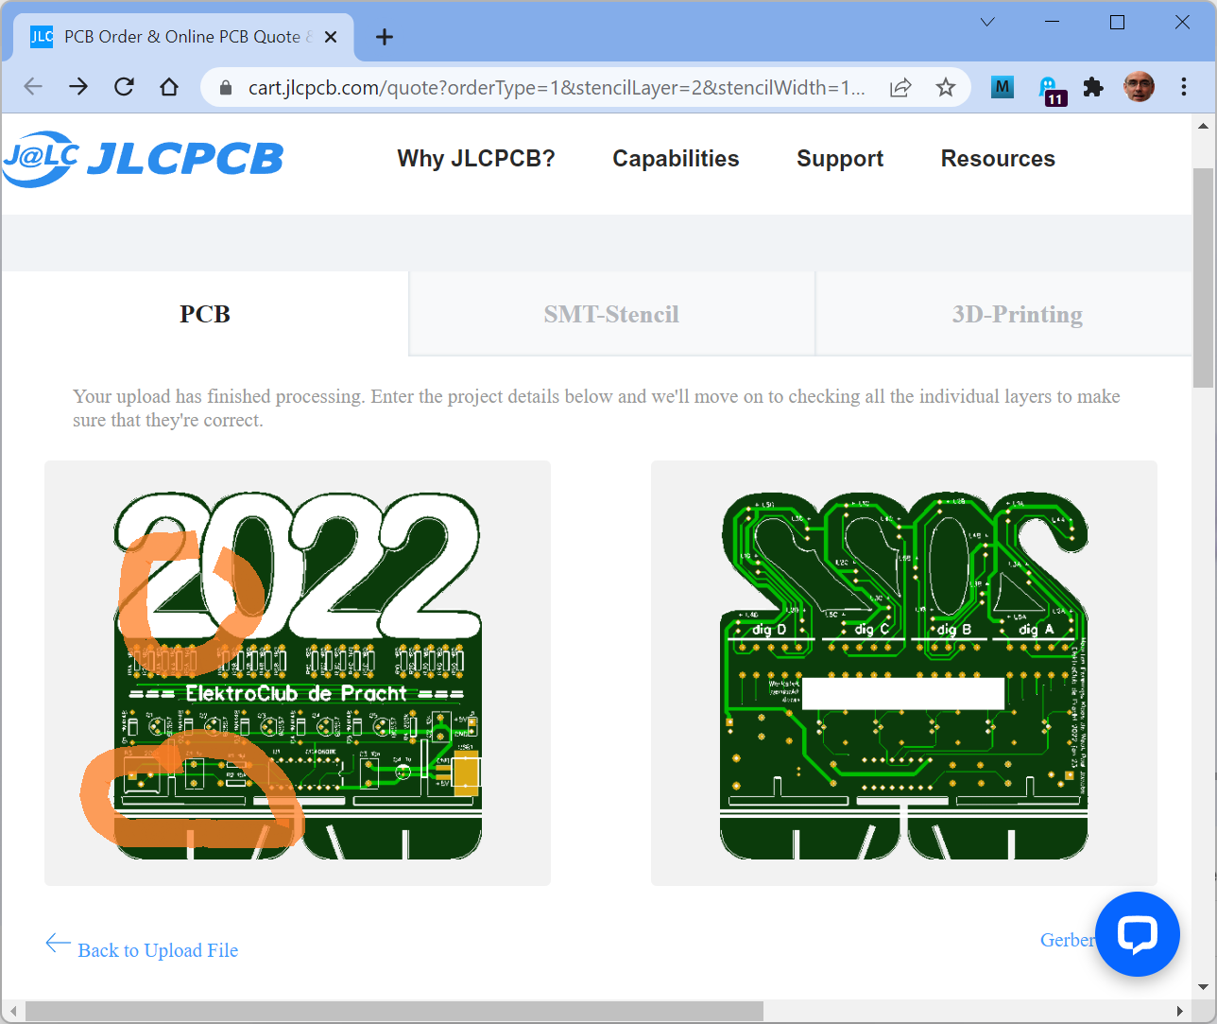
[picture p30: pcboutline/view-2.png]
Gerber in JLCPCB


No worries though, the end-result is still ok.

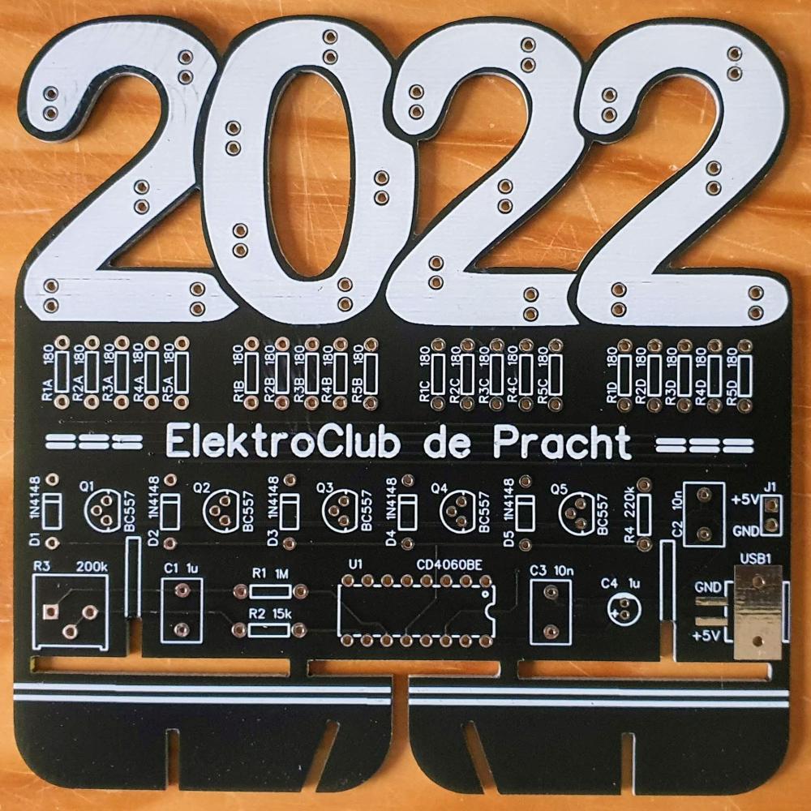
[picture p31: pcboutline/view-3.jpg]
Actual PCB


(end)

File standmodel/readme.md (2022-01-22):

# Stand model

I modeled (in [Fusion 360](https://www.autodesk.eu/products/fusion-360)) how the PCB could stand vertically using feet made as part of the PCB.

## Idea outline

The key idea is to use slots to join two planes.

The maximum PCB size of the "makers deal" at [JLCPCB](https://jlcpcb.com) is 100 _mm_ by 100 _mm_ (actually 4 _in_ by 4 _in_).
The two feet are made of a 15 _mm_ strip at the bottom (full length 0f 100 _mm_), 
so the main part is for the actual PCB: 83 _mm_ by 100 _mm_. Note that 15 plus 83 is 98, we have 2 _mm_ for separation slits.

I decided that each foot has _two_ slots: one straight and one at 70 degrees so that you have two options for the stand: 
straight and slanted.

concept

## Dimensions

The PCB thickness is 1.6 mm, to have a tight fit I made the slots 1.5 mm.
Worst-case we need to do some sanding to make them wider, and/or hot-glue to make them stay.

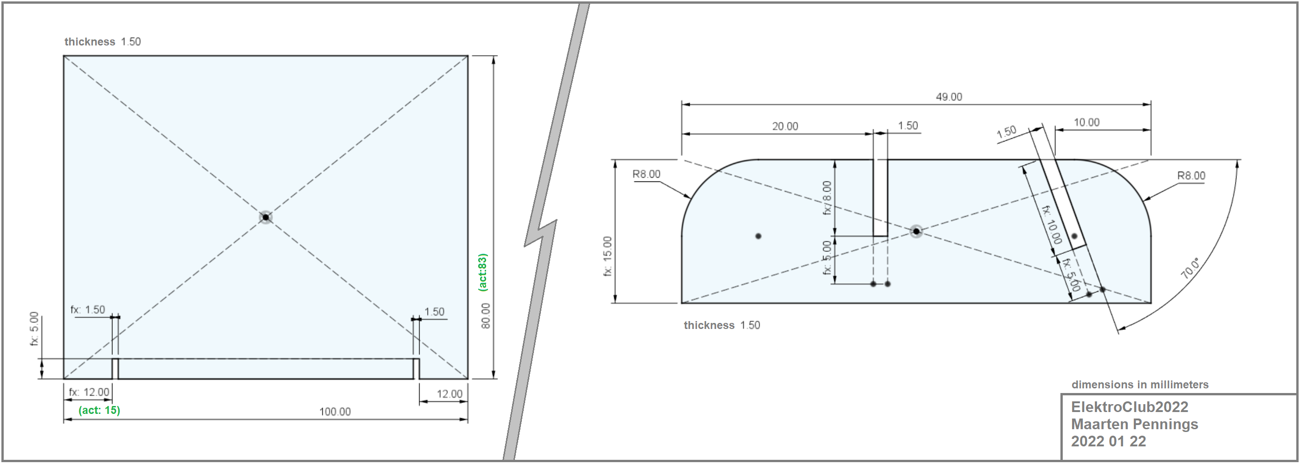
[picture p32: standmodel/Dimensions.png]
design


## Artist impression

Modeling the slanted and straight positions of the PCB 

slanted

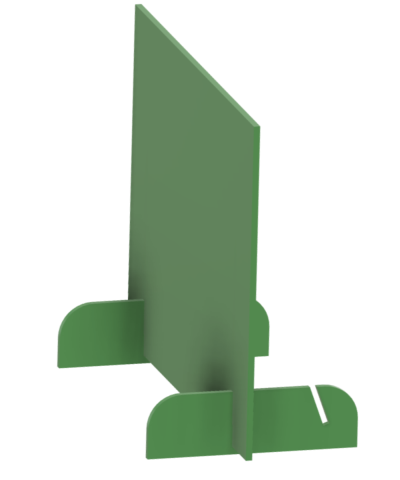
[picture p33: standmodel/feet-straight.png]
straight


## Next step

Next step is to create the actual "board outline" for the PCB.
This includes gaps for the digits. See [pcboutline](../pcboutline).

(end)

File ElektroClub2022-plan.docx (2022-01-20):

# Eindwerkstuk ElektroClub 2022

2022 jan 20 v4 Extra bestellingen na versie 1 van schema

2022 jan 13 v3 Bijgewerkt na avond in de Pracht

2022 jan 02 v2 Commentaar Klaas

2022 dec 30 v1 Verzoek Paul door Maarten

Paul vroeg naar een werkstuk voor de Elektroclub om het einde van het jaar (schooljaar dit keer, niet kalender jaar) te vieren. Paul suggereerde om iets als in 2014 te maken.

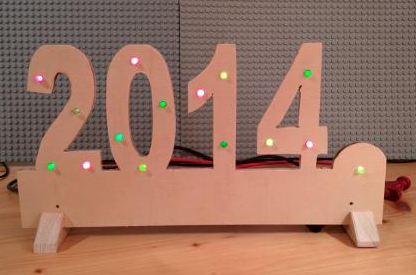
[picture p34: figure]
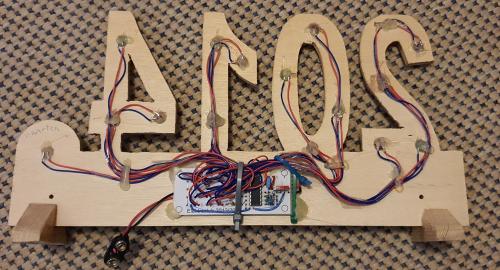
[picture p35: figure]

# Analyse

Het 2014 werkstuk bestond uit

- Door Paul voor-gezaagde triplex “2014” panelen
- Een stikker met layout op een standaard gaatjes print door Klaas/Maarten
- Componenten en LED-draden door kinderen te solderen
- Verlijmen (hot-glue) van LEDs, LED-draden, PCB, en paneel-voeten door vrijwilligers.

Ik kan het schema en de stikker thuis niet meer vinden. Het originele is van de "Kerstboom" uit de blauwe map van Paul. Het is gebaseerd op een 4060 “14 State Ripple Carry Binary Counter”, en lijkt sterk op https://circuits-diy.com/multiple-timing-led-flasher-using-cd4060-ic/ :


Verschillen: wij gebruiken alleen de onderste 5 IC uitgangen, en per uitgang hebben we een string van 3 LEDs.

# Overwegingen

- Het hout zagen, LED-draden solderen, en verlijmen, kost te veel tijd. Voorstel: PCB via JLCPCB. Zie hieronder een artist impressions: de cijfers met silk-print en een beetje de PCB uitgezaagd.


- Om het thuis demo vriendelijk te maken zou ik, net als in eerdere ElektroClub PCBs, een USB aansluiting willen gebruiken https://www.aliexpress.com/item/32931657320.html :


- Omdat hiermee de spanning voor de LED string te laag is stel ik voor de LEDs parallel aan te sturen met een transistor als voor versterker. Voorbeeld https://www.buildcircuit.com/diy-kit-8-happy-birthday-led-flashing-diy-kit-using-cd4060-and-music-chip/ :


Voorstel is om dit schema vrijwel identiek te volgen. Niet het geluid stuk, niet de power-schakelaar, wel de potmeter en de diodes (die doen een reset bij uit-uit-uit). Verder gaan wij 5 uitgangen met elk 4 LEDs (elk cijfer krijgt dus 5 LEDs) gebruiken (ipv 3 uitgangen met 4 LEDs).

# Actiepunten

- Maarten: PCB tekenen en bestellen

# Beslissingen, voltooide actiepunten

- Besteld door Maarten (na review Klaas)
  - 1uF ceramisch 100 samen met
  - 10nF ceramisch 100 voor €3.02 https://www.aliexpress.com/item/1005001715033995.htm
- Klaas: doorgerekend in plaats van prototype op breadboard
- Besteld door Maarten
  - 1N4148 geen 100 maar 200 voor €2.01 https://www.aliexpress.com/item/1005003540554760.html
  - CD4060 geen 20 maar 30 voor €2.52 https://www.aliexpress.com/item/1005001345739246.html
  - Cap 50V 1µF 4x7 geen 20 maar 50 voor €1.92 https://www.aliexpress.com/item/1005002842732971.html
  - Pot 200kΩ TH geen 20 maar 25 voor €5.48 https://www.aliexpress.com/item/32783054938.html
- Componenten keuze
  - diodes: bestellen 100×1N4148
  - 400 groene en 400 rode LEDs zijn beschikbaar
  - We gebruiken 1/8W weerstanden. 20×1MΩ (R1), 20×15kΩ (R2), 20×220kΩ (R4), 400×180Ω (LED) zijn beschikbaar
  - Transistor 100×BC557 beschikbaar
  - CD4060: bestellen 20×
  - Caps 20×1µF bestellen
  - geen aan/uit schakelaar (plug de USB stekker in/uit).
  - Potmeter: 20× 200kΩ PCB mount bestellen
- ElektroClub stopt midden juni, we beginnen dus met dit werkje midden mei – de deadline.
- Paul heeft nog 300 euro voor de Elektro+LEGO clubs, dus budget is geen probleem
- We kiezen voor 20 werkstukken: nu 5 elektro, 5 lego en 1 voor Klaas/Maarten/Paul en wellicht een paar voor kerst 2022. Schatting: 5 stuks is $2 + $4 shipping, 10 is $5 + $5 shipping, 15 is $12 + $10, 20 is $14 + $12
- Akkoord van Paul
- We gebruiken losse weerstanden (geen array https://www.aliexpress.com/item/32345194312.html): mooier, beter voor verschillende LEDs, beter uit te leggen, werk voor de kinderen.
- We schakelen de LEDs parallel en gebruiken transistor als stroomversterker.
- IC op voetjes. Besteld door Maarten 20 stuks voor € 1.75 (https://www.aliexpress.com/item/1005001403007175.html)
- Voeding door middel van USB plug. Besteld door Maarten 20 stuks voor € 2.00 (https://www.aliexpress.com/item/32931657320.html)
- Akkoord van Klaas (technisch en ondersteuning).

(eind)

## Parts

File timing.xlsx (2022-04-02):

Capacitor = 1uF |  |  |  |  | Capacitor = 220nF
C (F) = | 1e-06 |  | 1e-06 |  | C (F) = | 2.2e-07 |  | 2.2e-07
R (ohm) = | 15000 | (pot=0) | 215000 | (pot=200k) | R (ohm) = | 15000 | (pot=0) | 215000 | (pot=200k)
Fosc (Hz)= | 28.98550725 | 1/(2.3RC) | 2.022244692 |  | Fosc (Hz)= | 131.7523057 |  | 9.192021325
 | f (Hz) | T (s) | f (Hz) | T (s) |  | f (Hz) | T (s) | f (Hz) | T (s)
Q1 | 14.49275362 | 0.069 | 1.011122346 | 0.989 | Q1 | 65.87615283 | 0.01518 | 4.596010663 | 0.21758
Q2 | 7.246376812 | 0.138 | 0.5055611729 | 1.978 | Q2 | 32.93807642 | 0.03036 | 2.298005331 | 0.43516
Q3 | 3.623188406 | 0.276 | 0.2527805865 | 3.956 | Q3 | 16.46903821 | 0.06072 | 1.149002666 | 0.87032
(pin 7) Q4 | 1.811594203 | 0.552 | 0.1263902932 | 7.912 | (pin 7) Q4 | 8.234519104 | 0.12144 | 0.5745013328 | 1.74064
Q5 | 0.9057971014 | 1.104 | 0.06319514661 | 15.824 | Q5 | 4.117259552 | 0.24288 | 0.2872506664 | 3.48128
Q6 | 0.4528985507 | 2.208 | 0.03159757331 | 31.648 | Q6 | 2.058629776 | 0.48576 | 0.1436253332 | 6.96256
Q7 | 0.2264492754 | 4.416 | 0.01579878665 | 63.296 | Q7 | 1.029314888 | 0.97152 | 0.07181266661 | 13.92512
Q8 | 0.1132246377 | 8.832 | 0.007899393327 | 126.592 | Q8 | 0.514657444 | 1.94304 | 0.0359063333 | 27.85024
Q9 | 0.05661231884 | 17.664 | 0.003949696663 | 253.184 | Q9 | 0.257328722 | 3.88608 | 0.01795316665 | 55.70048
Q10 | 0.02830615942 | 35.328 | 0.001974848332 | 506.368 | Q10 | 0.128664361 | 7.77216 | 0.008976583326 | 111.40096
Q11 | 0.01415307971 | 70.656 | 0.0009874241658 | 1012.736 | Q11 | 0.0643321805 | 15.54432 | 0.004488291663 | 222.80192
Q12 | 0.007076539855 | 141.312 | 0.0004937120829 | 2025.472 | Q12 | 0.03216609025 | 31.08864 | 0.002244145831 | 445.60384
Q13 | 0.003538269928 | 282.624 | 0.0002468560415 | 4050.944 | Q13 | 0.01608304513 | 62.17728 | 0.001122072916 | 891.20768
Q14 | 0.001769134964 | 565.248 | 0.0001234280207 | 8101.888 | Q14 | 0.008041522563 | 124.35456 | 0.0005610364579 | 1782.41536
measured Q4 |  | 0.692 |  | 9.1 | measured Q4 |  | 0.131 |  | 1.67
ratio |  | 1.25 |  | 1.15 | ratio |  | 1.08 |  | 0.96

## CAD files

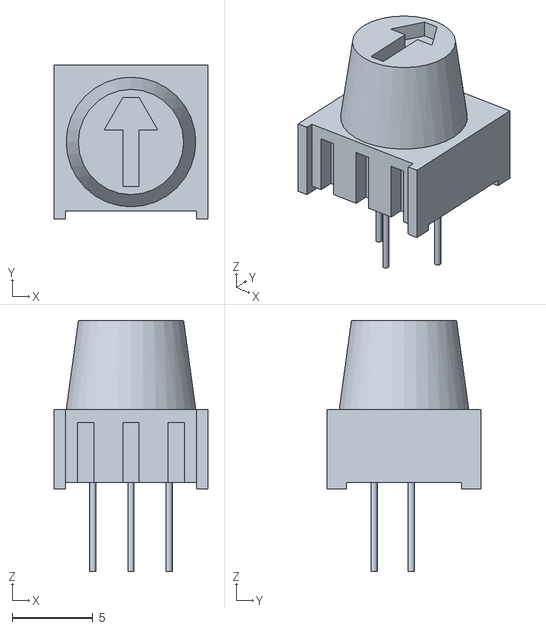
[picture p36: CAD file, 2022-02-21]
models/PotMeterBlue.obj
9.50 x 9.50 x 15.5

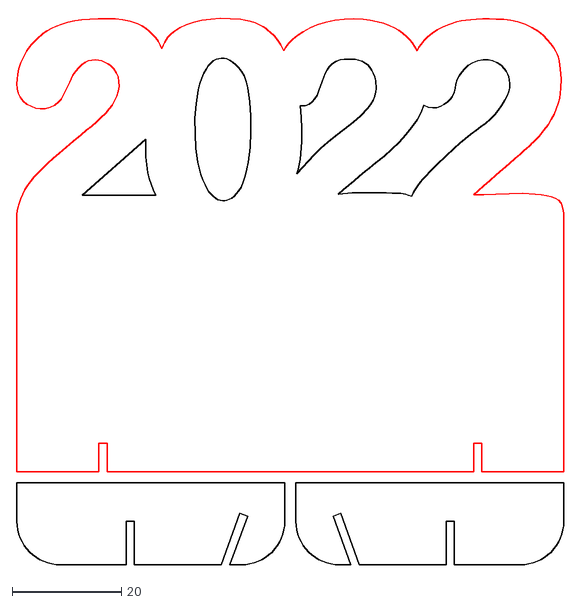
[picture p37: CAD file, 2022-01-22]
pcboutline/outline.dxf
100.4 x 100.3

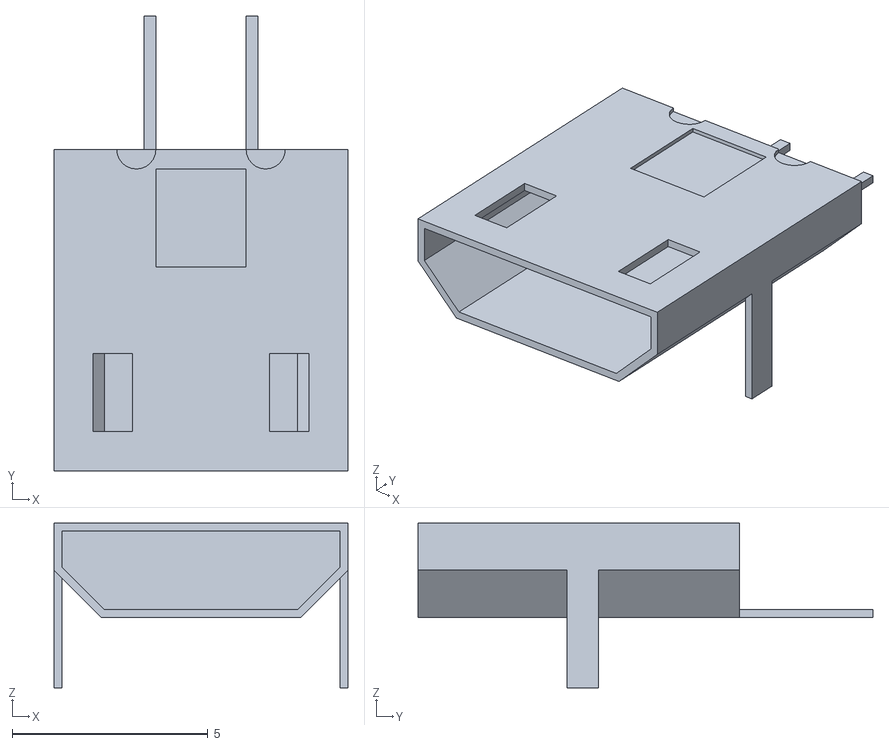
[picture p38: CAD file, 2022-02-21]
models/MicroUSB-2pin-power-only.obj
7.50 x 11.6 x 4.20

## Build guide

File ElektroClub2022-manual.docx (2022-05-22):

# Eindwerkstuk ElektroClub 2022

Maarten Pennings 2022 mei 22

# Schema

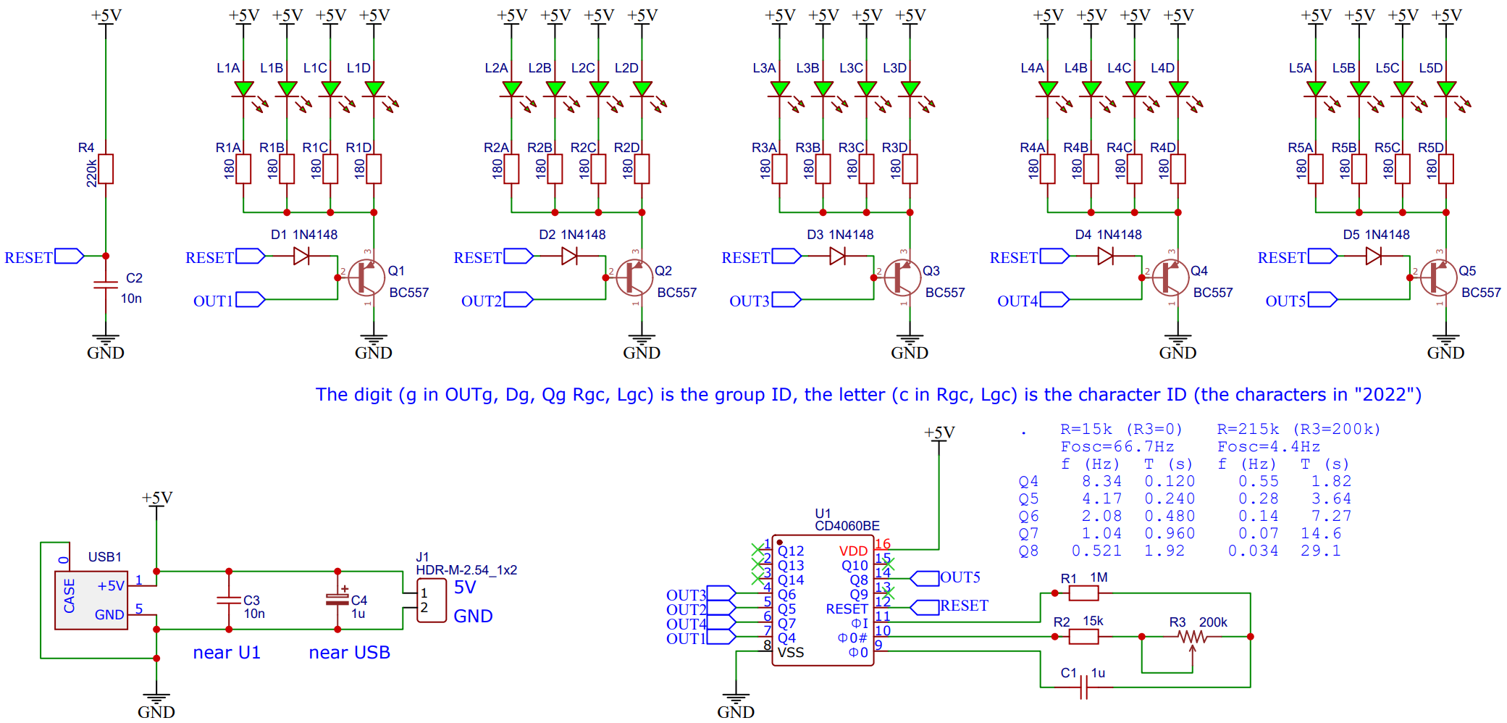
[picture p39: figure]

220nF

# Voor we beginnen met solderen

1. Schrijf achterop in het witte vlak je naam.
2. Maak de twee staanders los door de groen omcirkelde lipjes door te zagen.

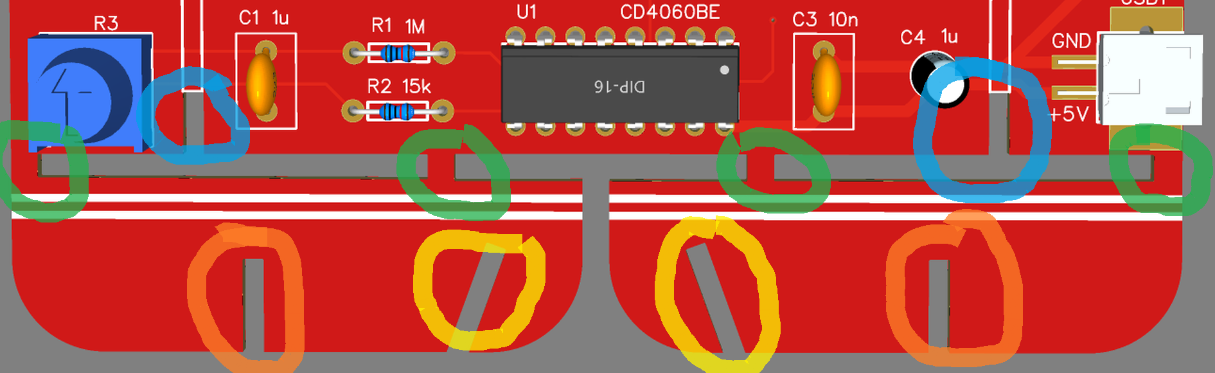
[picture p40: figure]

3. Schuur de afgezaagde lipjes glad, zowel bij de staanders als de hoofdprint.
4. De staanders schuiven met de gele sleuven in blauw (als je je werk scheef wil hebben staan) of ze schuiven met de oranje sleuven in blauw (als je je werk recht wil hebben staan).
5. Je moet de sleuven misschien iets breder maken voor een goede passing – met een schuurpapiertje of (nagel)vijl – of iets krapper – met een stukje plakband.
6. Haal de staanders los, ze zitten in de weg tijdens het solderen.

# Eindwerkstuk ElektroClub 2022

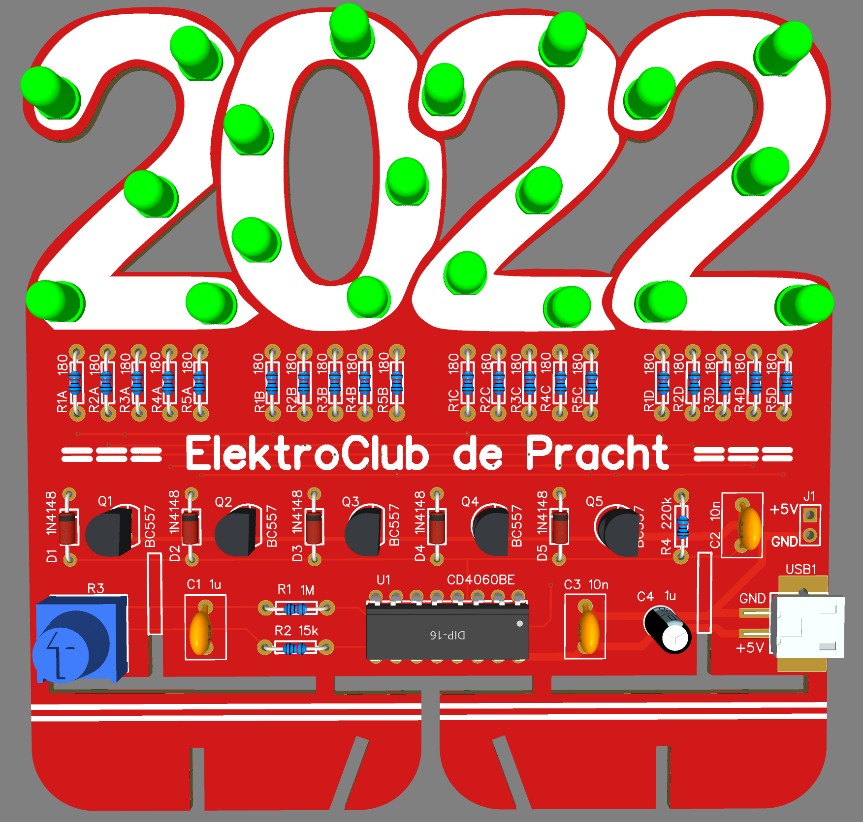
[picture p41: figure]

label | omschrijving | type | aantal
C1 | ceramische condensator | 1µF wordt 220nF | 1
C2, C3 | ceramische condensator | 10nF | 2
C4 | elektrolytische condensator | 1µF niet monteren | 1
D1, D2, D3, D4, D5 | diode | 1N4148 | 5
J1 (niet gemonteerd) | header | HDR-M-2.54-1x2 | 1
L1A, L1B, L1C, L1D, L2A, L2B, L2C, L2D, L3A, L3B, L3C, L3D, L4A, L4B, L4C, L4D, L5A, L5B, L5C, L5D | LED | LED-TH-5mm | 20
Q1, Q2, Q3, Q4, Q5 | transistor | BC557 | 5
R1 | weerstand | 1M | 1
R1A, R1B, R1C, R1D, R2A, R2B, R2C, R2D, R3A, R3B, R3C, R3D, R4A, R4B, R4C, R4D, R5A, R5B, R5C, R5D | weerstand | 180Ω | 20
R2 | weerstand | 15kΩ | 1
R3 | potentiometer | 200kΩ | 1
R4 | weerstand | 220kΩ | 1
U1 | weerstand | CD4060BE | 1
USB1 | connector | µUSB 2 pin power | 1

# Soldeer instructies

We werken van de kleinste onderdelen naar grootste.

1. Soldeer de diodes (D1..D5). Let op: diodes hebben een “polariteit” (richting): de streep op de diode komt waar de streep op de printplaat staat. Als je de eerste gesoldeerd hebt, laat even controleren.
2. Soldeer de weerstanden R1, R2 en R4. Let op hun waardes, ze zijn alle drie verschillend.
3. Soldeer de 20 weerstanden R1A..R5D (180Ω). Het is mooi als ze allemaal dezelfde kant op wijzen.
4. Soldeer de transistoren Q1..Q5. Let op: de platte kant als op de printplaat. Laat eerste transistor controleren.
5. Soldeer condensator C1. Dit is een ceramische (gele blob) met opdruk 224 (= 22 0000 pF = 220nF). Let op, op de printplaat staat 1 µF maar dan knipperen de LEDs te langzaam, vandaar de vervanging door 220 nF.
6. Soldeer condensatoren C2, C3, deze zijn ook ceramisch, opdruk 103 (= 10 000 pF = 10 nF).
7. Condensator C4 plaatsen we niet (niet beschikbaar en hopelijk niet nodig).
8. Soldeer de 20 LEDs. LEDs hebben een “polariteit” (richting): de ene poot is lang (plus) en de andere poot is kort (min). Op de achterkant van de printplaat zie je de plus aangegeven (voor alle LEDs aan de bovenkant). Als je de eerste 5 gesoldeerd hebt, laat even controleren (voor je de draden afgeknipt hebt).
9. Soldeer de IC-voet U1 – dus niet het IC zelf solderen! Let erop dat de IC-voet goed zit: er zit een ronde hap aan de korte kant die ook op de printplaat staat aangegeven.
10. Soldeer de micro USB-connector. Zowel de twee draadjes solderen, als de connector pinnen aan de onder en aan de bovenkant.
11. Soldeer de potentiometer R3.
12. Doe het IC in zijn voet U1. Let erop dat het IC er goed om in zit: in het IC zit een ronde hap die ook in het voetje en de printplaat zit. Je moet waarschijnlijk de pinnen iets naar elkaar toe buigen; vraag om hulp.
13. Schuif de printplaat met de sleuven in de staanders.
14. Vraag om hulp voor eindcontrole. Daar sluiten we een USB-adapter aan. De LEDs moeten gaan knipperen. Met R3 kun je de knippersnelheid regelen.
15. Je kunt ook via J1 voeden (5 Volt), let op plus en min.

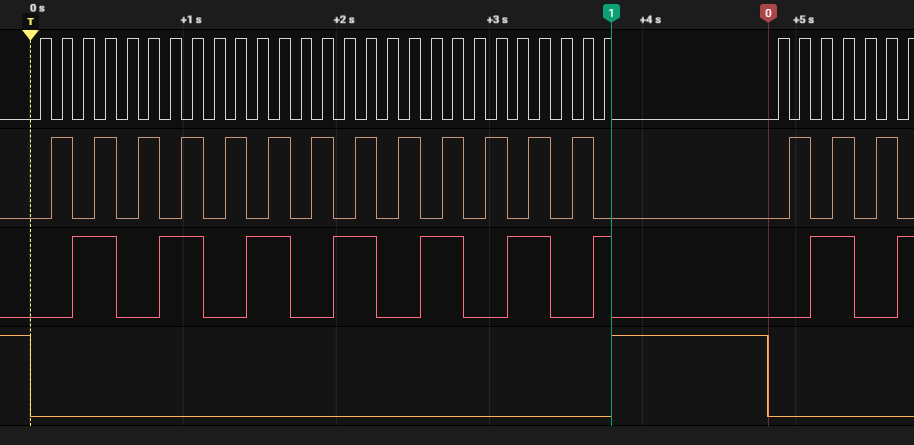
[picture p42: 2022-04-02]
debug/timing-manual-reset.png

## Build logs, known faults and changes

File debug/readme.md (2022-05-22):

# Debug

The PCB was not behaving completely as expected:
the timing was off, and although the external reset behavior was ok (no all-off LEDs) 
the logic analyzer showed a funny picture.

## Timing

On the logic analyzer we measured the frequency on output pin 7/Q4.

We started with the clock capacitor (C1) at 1µF and the potentiometer (R3) at min and max.

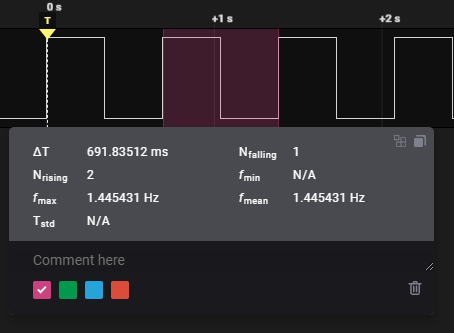
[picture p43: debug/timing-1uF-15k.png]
cap 1µF, pot at min (15k)


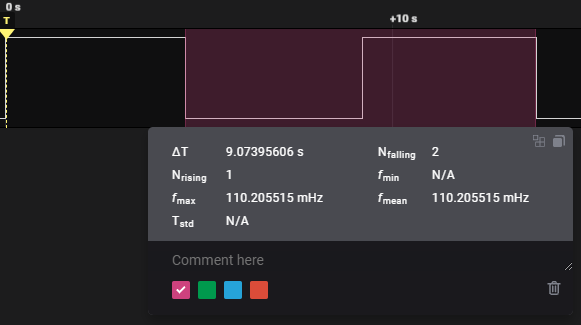
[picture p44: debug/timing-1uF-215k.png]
cap 1µF, pot at max (215k)


We measure a cycle time of 692ms respectively 9.1s.
That is about a factor 5 off what we planned. 

We replaced the clock capacitor (C1) with 5× smaller one: 220nF.
Now the logic analyzer gives us (with the potentiometer (R3) at min and max).

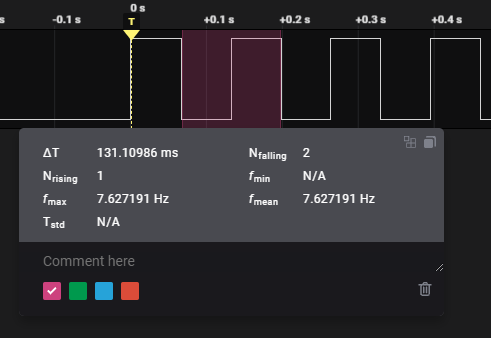
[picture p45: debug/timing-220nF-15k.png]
cap 220nF, pot at min (15k)


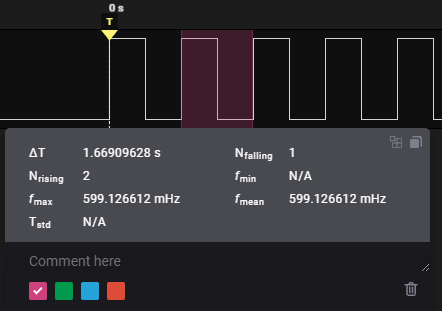
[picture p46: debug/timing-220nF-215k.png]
cap 220nF, pot at max (215k)


We made two errors.
 - We took as Fosc 1/RC. With 15kΩ en 1µF we get Fosc = 66.7Hz as in the original schematics.
   The datasheet (Nexperia HEF4060) explains that Fosc = 1/(2.3RC).
 - In the ST schematics Q4 de fourth divider, but in the Nexperia schematics Q4 de third.

The new timing computations - comparing the 1µF case (left) with the 220nF case (right) - are as follows.

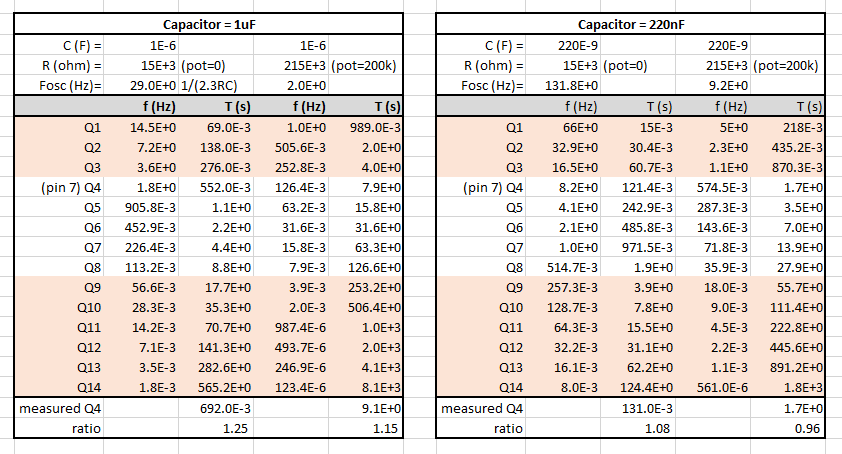
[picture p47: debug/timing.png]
Timing


# Reset

I made a smaller version of the system with just 4 outputs.

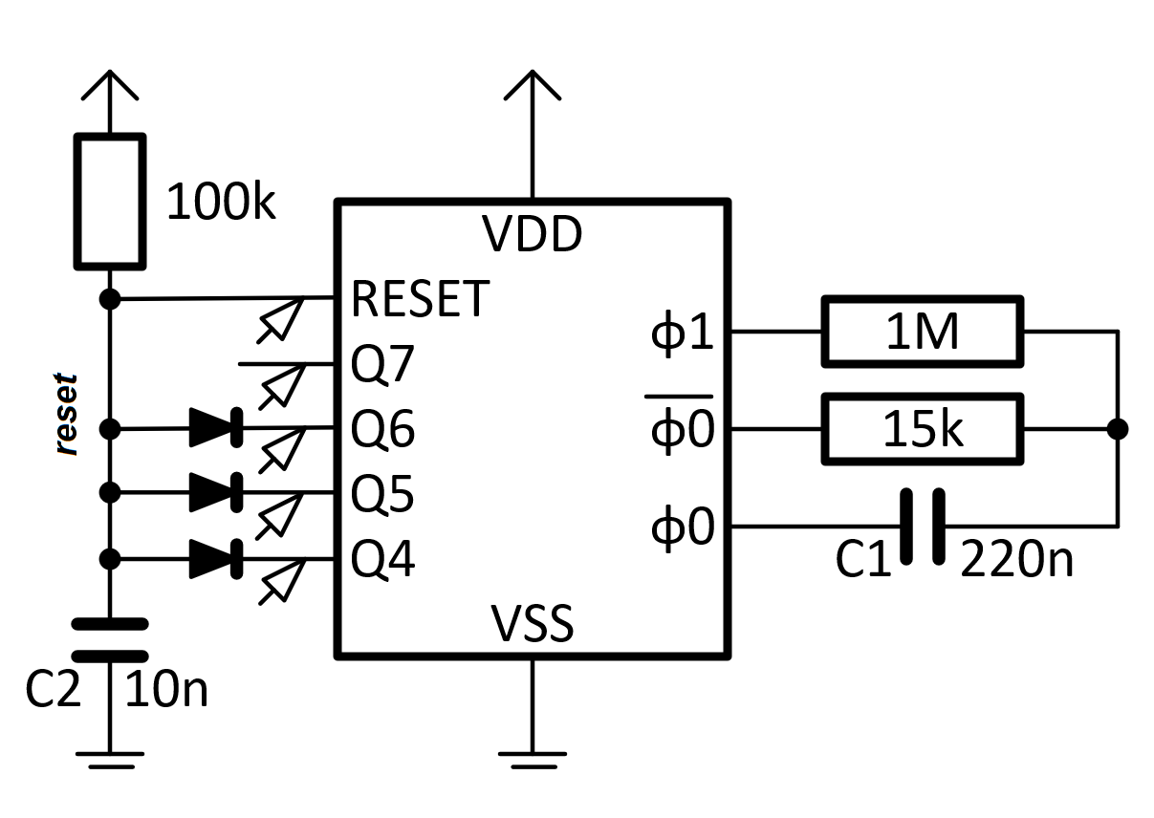
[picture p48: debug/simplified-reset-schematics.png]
simplified reset schematics


The arrows show where the probes of the logic analyzer are.

Recall that the chip resets when the RESET pin goes high. 
It is connected to a pull-up.
But as long as one of Q4, Q5, or Q6 is low, the _reset_ net is low.
Only when all Qs are high, the _reset_ net goes high and thus the RESET pin, so that the chip resets.

These are the Saleae traces [with C2](timing-with-C2.sal) and [without](timing-no-C2.sal), 
and here are a screenshots of these traces.

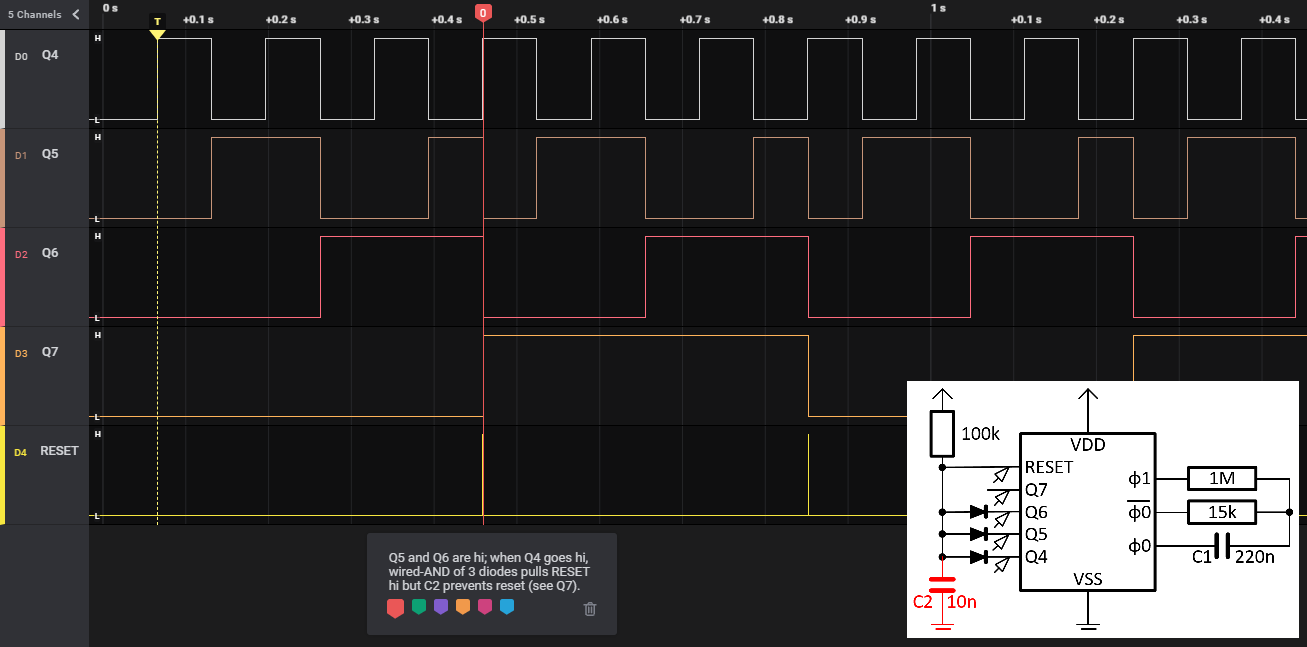
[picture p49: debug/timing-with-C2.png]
Reset with C2 present


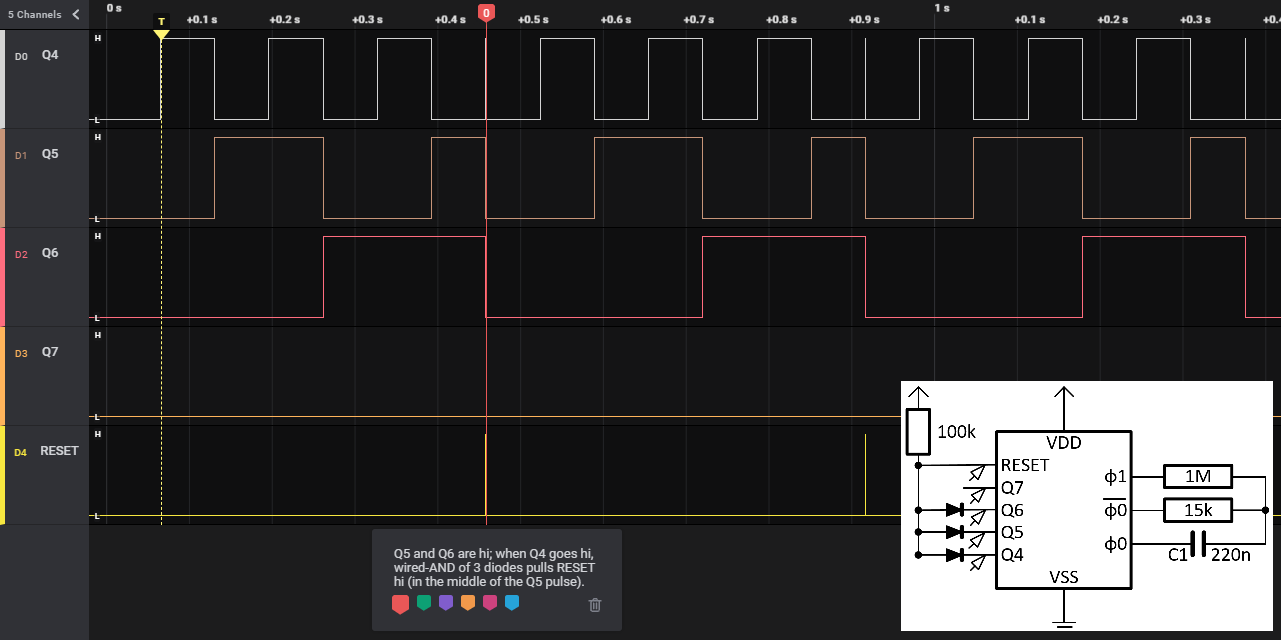
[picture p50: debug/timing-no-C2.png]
Reset without C2


The C2 prevents a "full" reset of all outputs.

What probably happens is that when all lines are hi, the chips starts to reset.
One of the outputs is reset first (depending on chip design, maybe varies per batch),
this cause the _reset_ net to go low, and this prevents other output stages to reset.

We removed the C2 from the real board.

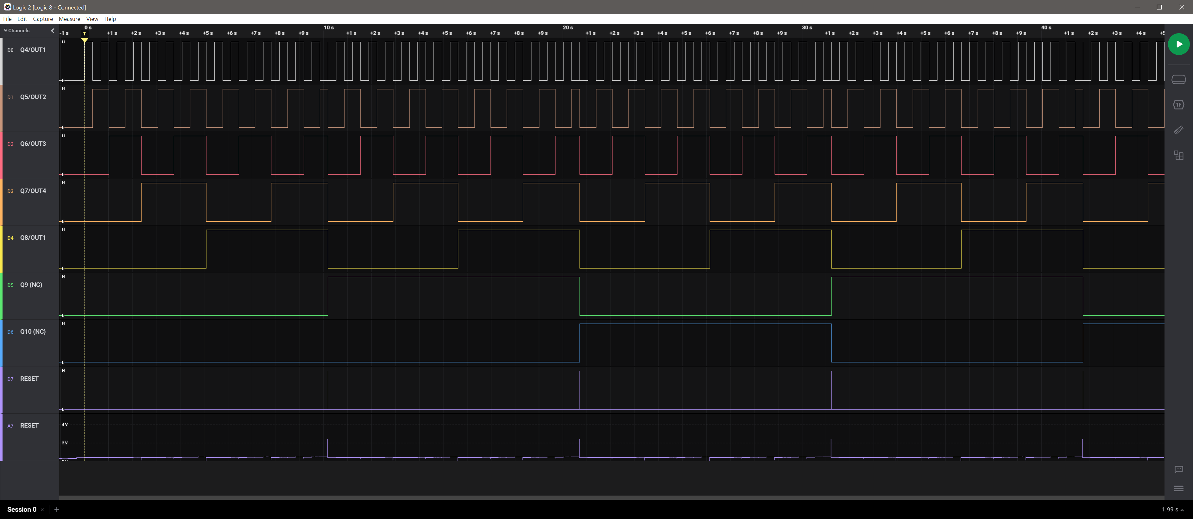
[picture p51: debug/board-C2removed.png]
C2 removed


Around 10ms, the reset comes (see D7, but note that the A7 is rather low) as D1/Q5/OUT2 is aborted.
But D5/Q9 stays high. It even appears that D6/Q10 has become the inverse of D5/Q9.

As a next step, we lowered R4 (the pull-up for RESET) from 220k to 10k.
This finally gives the expected trace. Still, the spike in A7 is rather low.
That makes sense, because immediately after reset the RESET line is de-asserted.

# Conclusions

 1. Clock capacitor C1 must be changed to 220nF
 2. Reset pull-up R4 could be changed to 10k - but without this change it does a partial reset
 3. Reset capacitor C2 could be removed - but without this change it does a partial reset

Only 1 is really necessary, shall we also do the other two errata?

(end)

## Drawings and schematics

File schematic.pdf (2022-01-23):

+5V220k

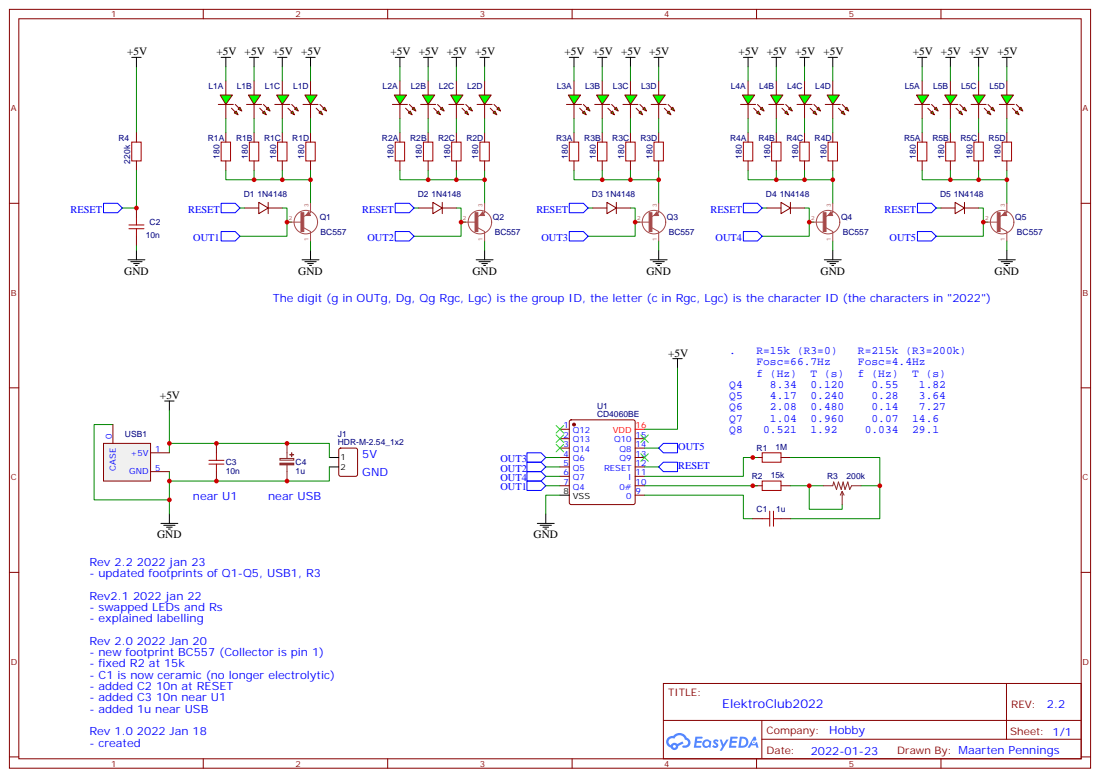
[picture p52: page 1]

GND
The digit (g in OUTg, Dg, Qg Rgc, Lgc) is the group ID, the letter (c in Rgc, Lgc) is the character ID (the characters in "2022")

Rev 2.2 2022 jan 23
- updated footprints of Q1-Q5, USB1, R3
Rev2.1 2022 jan 22
- swapped LEDs and Rs
- explained labelling
Rev 2.0 2022 Jan 20
- new footprint BC557 (Collector is pin 1)
- fixed R2 at 15k
- C1 is now ceramic (no longer electrolytic)
- added C2 10n at RESET
- added C3 10n near U1
- added 1u near USB
Rev 1.0 2022 Jan 18
- created

Drawn By: Maarten Pennings

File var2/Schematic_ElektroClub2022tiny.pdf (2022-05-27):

+5V220k

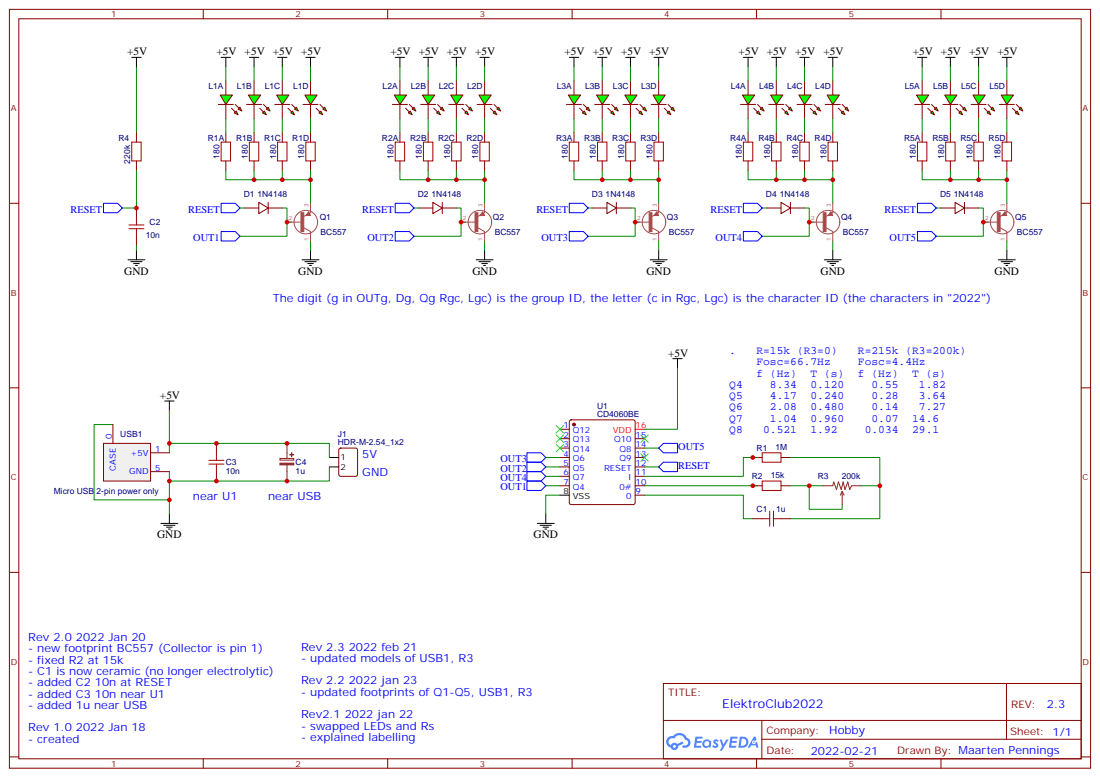
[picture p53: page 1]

GND
The digit (g in OUTg, Dg, Qg Rgc, Lgc) is the group ID, the letter (c in Rgc, Lgc) is the character ID (the characters in "2022")

Micro USB 2-pin power only

Rev 2.0 2022 Jan 20
- new footprint BC557 (Collector is pin 1)
- fixed R2 at 15k
- C1 is now ceramic (no longer electrolytic)
- added C2 10n at RESET
- added C3 10n near U1
- added 1u near USB
Rev 1.0 2022 Jan 18
- created

Rev 2.3 2022 feb 21
- updated models of USB1, R3
Rev 2.2 2022 jan 23
- updated footprints of Q1-Q5, USB1, R3
Rev2.1 2022 jan 22
- swapped LEDs and Rs
- explained labelling

Drawn By: Maarten Pennings

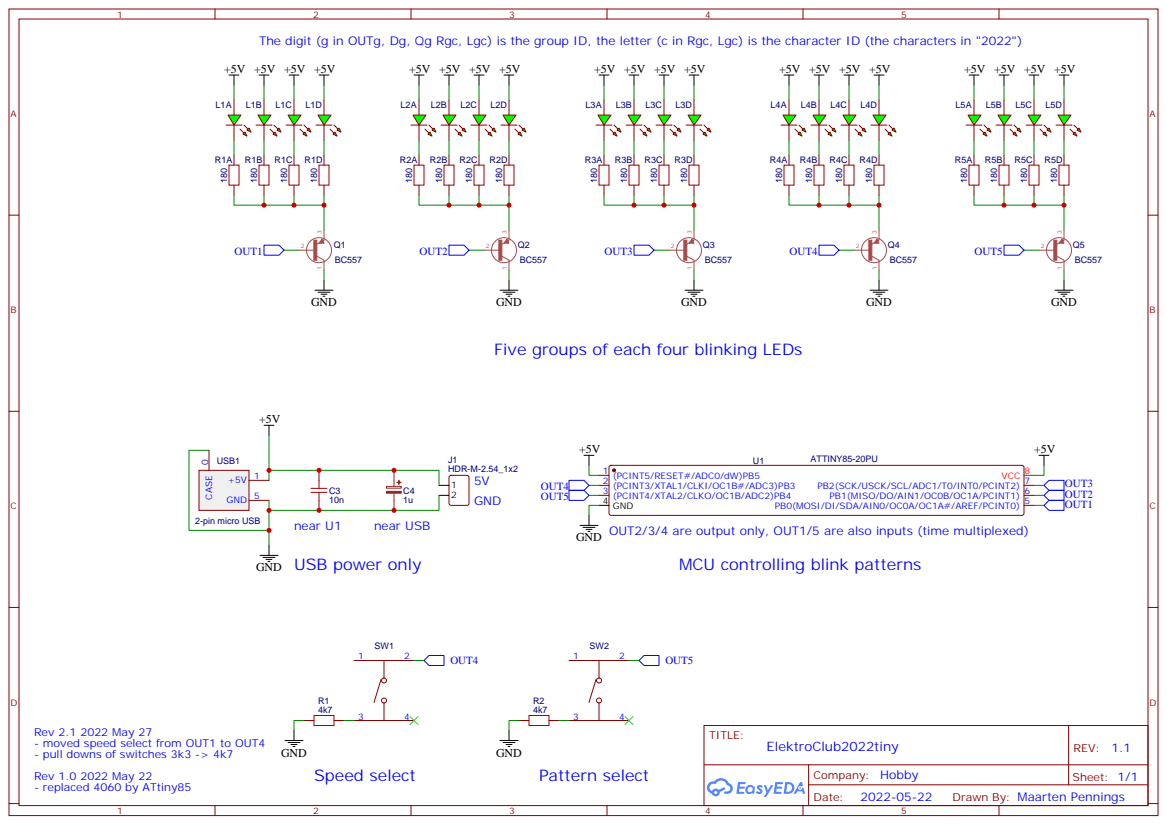
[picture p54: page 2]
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

Five groups of each four blinking LEDs

PB0(MOSI/DI/SDA/AIN0/OC0A/OC1A#/AREF/PCINT0)

OUT2/3/4 are output only, OUT1/5 are also inputs (time multiplexed)
GND

Rev 2.1 2022 May 27
- moved speed select from OUT1 to OUT4
- pull downs of switches 3k3 -> 4k7
Rev 1.0 2022 May 22
- replaced 4060 by ATtiny85

Drawn By: Maarten Pennings

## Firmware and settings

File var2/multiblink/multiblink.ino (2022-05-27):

// multiblink.ino - sketch to blink 5 LEDs randomly (multiple modes and speeds)
// https://github.com/SpenceKonde/ATTinyCore


// === led ========================================


#define LED_0       1
#define LED_1       2
#define LED_2       4
#define LED_3       8
#define LED_4      16
#define LED_ALL    31


#if 0 // Nano
  #define LED_0_PIN   2
  #define LED_1_PIN   3
  #define LED_2_PIN   4
  #define LED_3_PIN   5
  #define LED_4_PIN   6
#endif
#if 1 // ATtiny
  #define LED_0_PIN   0
  #define LED_1_PIN   1
  #define LED_2_PIN   2
  #define LED_3_PIN   3
  #define LED_4_PIN   4
#endif


void led_init() {
  pinMode( LED_0_PIN, OUTPUT );
  pinMode( LED_1_PIN, OUTPUT );
  pinMode( LED_2_PIN, OUTPUT );
  pinMode( LED_3_PIN, OUTPUT );
  pinMode( LED_4_PIN, OUTPUT );
}


void led_set(uint8_t leds ) {
  digitalWrite( LED_0_PIN, (leds&0x01)==0 );
  digitalWrite( LED_1_PIN, (leds&0x02)==0 );
  digitalWrite( LED_2_PIN, (leds&0x04)==0 );
  digitalWrite( LED_3_PIN, (leds&0x08)==0 );
  digitalWrite( LED_4_PIN, (leds&0x10)==0 );
  
}


// === but ========================================


#define BUT_0       1
#define BUT_1       2
#define BUT_ALL     3


#define BUT_0_PIN   LED_3_PIN
#define BUT_1_PIN   LED_4_PIN


// Call but_scan() in every loop
uint8_t  but_prv;  // button state in previous call to but_scan()
uint8_t  but_cur;  // button state in current call to but_scan()


void but_scan() {
  but_prv = but_cur;
  but_cur = 0;
  
  // BUT_0 is shared with a LED, so we temporarily steal the pin, but set it back
  uint8_t restore0=digitalRead(BUT_0_PIN);
  pinMode(BUT_0_PIN, INPUT_PULLUP);
    if( digitalRead(BUT_0_PIN)==0 ) but_cur |= BUT_0; // Low-active
  pinMode(BUT_0_PIN, OUTPUT);
  digitalWrite(BUT_0_PIN,restore0);

  // BUT_1 is shared with a LED, so we temporarily steal the pin, but set it back
  uint8_t restore1=digitalRead(BUT_1_PIN);
  pinMode(BUT_1_PIN, INPUT_PULLUP);
    if( digitalRead(BUT_1_PIN)==0 ) but_cur |= BUT_1; // Low-active
  pinMode(BUT_1_PIN, OUTPUT);
  digitalWrite(BUT_1_PIN,restore1);
}


void but_init() {
  // The buttons pins are shared with the LEDs', so we set the input mode during readout only
  but_scan();
  but_scan();
}


uint8_t but_wentdown(uint8_t buts) {
  return (but_prv^but_cur) & but_cur & buts;
}


// === mode ===========================================


#define MODE_ALL       0
#define MODE_HALF      1
#define MODE_BIN       2
#define MODE_WALK1     3
#define MODE_WALK2     4
#define MODE_FILL      5
#define MODE_RND       6
#define MODE_RNDMED    7
#define MODE_COUNT     8


// Which animation mode, wich substate, and how long for one animation step
uint8_t mode = MODE_RNDMED;
uint8_t state = 0;
uint8_t wait100ms = 8;


#if 0 // 1 for Serial support
  #warning Compiled with serial support
  const char * mode_names[MODE_COUNT]={"all","half","bin","walk1","walk2","fill","rnd","rndmed"};
  void print_mode() {
    Serial.print("mode="); Serial.print(mode); Serial.print("="); Serial.print(mode_names[mode]);
    Serial.print("  wait100ms="); Serial.println(wait100ms);
  }
  void print_init() {
    Serial.begin(115200);
    Serial.println("\n\n");
    Serial.println("Welcome to multiblink");
  }
#else
  #warning Compiled without serial support
  #define print_mode() (void)0
  #define print_init() (void)0
#endif


const uint8_t popcount[32]={0,1,1,2,1,2,2,3,1,2,2,3,2,3,3,4,1,2,2,3,2,3,3,4,2,3,3,4,3,4,4,5};


// === main ====================================================


uint32_t last_step;
void setup() {
  print_init();
  led_init();
  last_step = millis();
  print_mode();
}


void loop() {
  
  but_scan();
  delay(10); // debounce
  if( but_wentdown(BUT_0) ) {
    wait100ms = wait100ms*2;
    if( wait100ms>64 ) wait100ms=1;
    print_mode();
  }
  if( but_wentdown(BUT_1) ) {
    mode = (mode+1) % MODE_COUNT;
    print_mode();
  }
    
  if( millis()-last_step > 100*wait100ms ) {
    // Next animation step  
    static uint8_t mask;
    uint8_t rev;
    
    switch( mode ) {
      
    case MODE_ALL:
      state = (state+1)%2; // Next step, but also clip for current mode
      mask = LED_ALL;
      rev = state;
      led_set( rev ? ~mask : mask );
      break;
      
    case MODE_HALF:
      state = (state+1)%2;
      mask = LED_3+LED_4;
      rev = state;
      led_set( rev ? ~mask : mask );
      break;
      
    case MODE_BIN:
      state = (state+1)%32;
      mask = state;
      led_set( mask );
      break;
    
    case MODE_WALK1:
      state = (state+1)%5;
      mask = 1<<state;
      led_set( mask );
      break;
    
    case MODE_WALK2:
      state = (state+1)%5;
      mask = 1<<state;
      mask |= 1<<((state+1)%5);
      led_set( mask );
      break;
    
    case MODE_FILL:
      state = (state+1)%10;
      mask = state % 5;
      rev = state / 5;
      mask = (1<<mask) - 1;
      led_set( rev ? 31-mask : mask);
      break;
    
    case MODE_RND:
      state = random(0,32);
      if( state==mask ) state = (state+1)%32; // no duplicates
      mask = state;
      led_set( mask );
      break;
  
    case MODE_RNDMED:
      state = random(0,32); 
      while( popcount[state]<2 || popcount[state]>3 || state==mask ) state = (state+1)%32;
      mask = state;
      led_set( mask );
      break;
  
    }
    last_step = millis();
  }
  
}

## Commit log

2022-01-20 Created repo
    [timing.xlsx]
2022-01-20 Plan v4 (for schematic v2)
2022-01-22 move to pcboutline
    [outline.dxf]
2022-01-22 Outline updated
    [outline.dxf]
2022-01-22 schematic and pcb
2022-01-22 slot mark
2022-02-20 board outline explained
2022-02-21 added PCB component models
    [MicroUSB-2pin-power-only.obj, PotMeterBlue.obj]
2022-03-10 added BOM
2022-04-02 debug - timing 5x longer than expected - reset not happening
    [timing.xlsx]
